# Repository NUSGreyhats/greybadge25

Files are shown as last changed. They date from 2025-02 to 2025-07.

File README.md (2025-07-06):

# greybadge25
GreyCTF 2025 Badge (Greymecha Army)

1. [Instruction Manual](https://docs.google.com/presentation/d/1nLdjBvxjxtfjGmfyWnxctUPe7XqL7leBmsDQaAjqEwk/edit?usp=sharing)
2. [Slides for Badge Talk](https://docs.google.com/presentation/d/1yoPuX5LA_Zj3ds3s_bZVRaBWZWmjrsSOJFy59PNaYqE/edit?usp=sharing)

## Repository Structure
```
.
├── firmware
│   ├── circuitpython_frozen_leaky.uf2  # CircuitPython firmware to flash
│   ├── ecp5                            # FPGA-related files                   
│   └── rp2350
│       ├── art                         # Greycat animation files (thanks shuqing!)
│       ├── filesystem                  # Filesystem to copy into CircuitPython (includes challenges)
│       ├── solutions                   # Solution scripts
│       └── src_chall                   # Raw challenge files for reference
├── hardware
│   ├── artwork                         # Artwork used on the PCB (thanks shuqing!)
│   ├── fpga_placement.svg              # High level reference for how the FPGA pins were used
│   ├── greybadge_pcb                   # KICAD files
│   ├── JLCPCB.kicad_dru
│   └── kicad_libraries
└── README.md
```

## Firmware Set Up Guide
1. Connect the PCB to your computer. It will mount as a USB drive named RPI_RP2.
2. From the `/firmware` folder, drag & drop the file `circuitpython_frozen_leaky.uf2` onto the RPI_RP2 drive.
3. This should restart the badge and it will appear as a new USB drive called CIRCUITPYTHON.
4. Open `/firmware/rp2350/filesystem` on your computer and copy everything inside that folder to the CIRCUITPYTHON drive.
5. Your badge is set up!

## Hardware Ordering Guide
Refer to `Prototype 3 Order` under Releases.

Feel free to update the BOM to remove the oscillator for the FPGA as it is expensive and not strictly necessary.

Ordering on JLCPCB:
1. Upload the GERBER into the order page.
2. For the PCB Fab options, we recommend mostly using the defaults, but keep the following options in mind:
    - Finishing: HASL (HASL is fine, though we recommend ENIG for higher quantities as the extra cost scales well and is better for BGA soldering.)
    - To customize the main PCB colour, update the soldermask colour.
    - To have it assembled, tick the option below. You would likely want to choose to assemble both sides, which requires the standard assembly (not economic assembly).
3. Select the BOM/CPL if you chose to have it assembled.

There are several things you will need to order separately (and solder on).
1. Screen: [Taobao Link](https://item.taobao.com/item.htm?id=784228754299), choose the 焊接12P option.
2. Battery: You can either use a LIPO with JST-PH connector or solder 3x AA batteries.
    - LiPo Battery: [Taobao Link](https://item.taobao.com/item.htm?id=695205775685) We chose the 603040-750mAh option. If you want to have the plug rather than soldering the battery, contact the seller to install the 2.0-2P 反向公插 header (2.0mm pitch, 2 pin, reverse-orientation), which is essentially JST-PH, on the battery.
    - AA Battery Holder: [Taobao Link](https://detail.tmall.com/item.htm?id=533054527075).
    - 90 Degree Pinout Headers (or just solder wires)

## FPGA Tooling

A sample FPGA project is in `/firmware/ecp5/uart_coprocessor`. The tooling needed to be installed is as such

```
sudo apt install openFPGALoader # only needed if you use an external fpga jtag programmer
sudo apt install yosys
sudo apt install nextpnr-ecp5
sudo apt install fpga-trellis
```

Afterwards, you can just run `make clean` and `make` to generate the bitstream.

You can upload through the RP2350 in the `hardware.fpga` libraries

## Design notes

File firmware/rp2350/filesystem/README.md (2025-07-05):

# GreyMecha/Army

This is the GreyMecha/Army Firmware (for the RP part anyway). It's based off circuitpython, and includes various challenges.

## Images

To customise the badge with your own (`.jpg` and `.gif`), just put them in the `images` folder. 
Make sure they are 240x240 pixels.

You may use EzGif to convert a video to Gif format. https://ezgif.com/video-to-gif

You may also use EzGif to resize to 240 x 240 pixels. https://ezgif.com/maker

## Challenges

There are 2 kinds of challenges. 
`grey` challenges are ones which are released for GreyCTF 2025 Finals. If you are a finalist, you only need to care about these.
`fun` challenges, meanwhile, are just ones for fun. 

Grey Challenges
1. Hornet Revenge
2. Leaky Pin
3. Bricked Up
3. Shooting Flags
4. Secure Memory
5. CatCore

## Updates

This badge might receive firmware updates so do check NUS Greyhats Github for any updates!
https://github.com/NUSGreyhats

Can also check the creator's blog for eventual solutions and writeups!
https://hackin7-blog.vercel.app/

## Credits

Developers

1. Hackin7 
    - Main Badge System Designer
    - Concept, Artwork & Animations
    - PCB (Power, FPGA, Connectivity)
    - Firmware
2. itsme-zeix 
    - PCB (RP2350, LiPo, Power), Leaky Pin, Firmware
3. shuqing 
    - Artwork & Animations (They are so cute man)
4. Fieash
    - Bricked Up Challenge
5. sunshinefactory
    - zip file
6. Codekrodile
    - mirrortune
7. khian
    - Asteroids
8. sayomaki
    - Bad Apple

Thanks to these people for helping

1. zst123, rhgndf, sayomaki - Technical Advice
2. caprinux - For initiating the whole GreyHats Badge thing

and thanks to GreyHats and whoever else who made this possible!

For anyone who made anything cool with the badge, do share it on instagram/x and tag NUSGreyhats!

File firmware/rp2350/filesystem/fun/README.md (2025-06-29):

# Fun Challenges

### SMD Skills

Get a 48MHz oscillator from the staff. You can solder it to the badge, read the flag from UART.
Make sure to set the Solder Bridge to the right option. If in doubt ask Hackin7.

Once soldered, go to UART mode and send "@---------------B@" to the UART

### SunshineZip (sunshinefactory)

Check the zip.

### Fast Secure Memory (hackin7)

Secure Memory but at 50MHz instead of 10Hz
(Untested lmao but theoretically can work)

### Bricked Up Game v2 (Fieash/itsme-zeix)

Updates the Bricked Up Challenge to remove the challenge and add additional features to the gameplay more NES Tetris-like.

Replace `brick_game.mpy` in `/apps` with the `brick_game.py` found in this directory.

Changes include:
- Removal of Konami code for CTF challenge
- Addition of J, S and Z pieces
- Additon of Ghost piece (to aid gameplay)
- Addition of background music: Tetris theme song played with the buzzer
- Level system: Increases with score
- Gameplay/Music multipler: Increases (speeds up) with levels

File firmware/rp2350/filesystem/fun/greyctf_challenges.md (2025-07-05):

# Challenges

Challenges can be found at https://github.com/NUSGreyhats/greyctf25-challs-public/tree/main/finals/hardware 

## Hornet Revenge

### Details

I want revenge.

Stop the backend and run this in the Thonny REPL to start the challenge.

```python
from hornet_revenge import *
```

### Author

Hackin7

## Bricked Up

### Details
Hardware/Reverse

A classic game of brick! 

### Author
fieash

## Leaky Pin

### Details

I wonder if there's something special in the secret pin....

Stop the backend and run this in the Thonny REPL to start the challenge.

```python
from leaky_gpio25 import *
```

### Author

itsme-zeix

## Shooting Flags

### Details

We have some Secure Armed Forces (SAF) on our badge. They are well trained to follow instructions and patterns.

```verilog
module shooting_flags #(
    parameter CLK_FREQ = 48_000_000 // not the actual clock frequency
) (
    input clk, input got_commanding_officer, output [7:0] cats
);
    //// Shooting Rate ////////////////////////////////////////////////////
    // Create a new clock
    reg [31:0] counter_shooting = 0;
    reg clk_shooting = 0;
    always @ (posedge clk) begin
        counter_shooting <= counter_shooting + 1;
        if (counter_shooting == CLK_FREQ/30) begin
            clk_shooting <= ~clk_shooting;
            counter_shooting <= 0;
        end
    end
    
    reg [31:0] counter_wayang = 0;
    reg clk_wayang = 0;
    always @ (posedge clk) begin
        counter_wayang <= counter_wayang + 1;
        if (counter_wayang == CLK_FREQ/4) begin
            clk_wayang <= ~clk_wayang;
            counter_wayang <= 0;
        end
    end
    //// Shooting /////////////////////////////////////////////////////////
    localparam FLAG_LEN = 25;
    reg [7:0] flag[FLAG_LEN];
    always @ (*) begin
        // lmao no flag
    end

    reg [7:0] shooting = 8'b101;
    reg [7:0] shooting_flag = 8'b0;
    reg [$clog2(FLAG_LEN)-1:0] counter_display = 0;
    always @ (posedge clk_shooting) begin
        shooting <= shooting << 1 | shooting[7];
    end
    always @ (posedge clk_wayang) begin
        shooting_flag <= (
            flag[counter_display] << counter_display % 8 | 
            flag[counter_display] >> (8-counter_display%8)
        );
        counter_display <= (counter_display + 1) % FLAG_LEN;
    end
    /// LED output //////////////////////////////////////////////////////
    assign cats = (got_commanding_officer ? shooting_flag : shooting);

endmodule

/* in the top module it is used as such

wire [7:0] chall_shootingflags_leds;
shooting_flags #(.CLK_FREQ(CLK_FREQ)) chall_shootingflags (
    .clk(clk), 
    .got_commanding_officer(~btn[2]),
    .cats(chall_shootingflags_leds)
);

*/
```

### Author

Hackin7

## Secure Memory

### Details

It's security at the hardware level so it must be secure right?

Clock Frequency - 15Hz

Verilog Reference

```verilog
// Code your design here
module regular_synchronous_memory(input clk, input [4:0] address, output reg [7:0] value);
	// memory retrieval
	always @ (posedge clk) begin // 10Hz
		value <= (
            // lmao you think i'll just give you the flag here? go extract it from your catcore.
			0
		);
	end
endmodule

module secure_memory(input clk, input [4:0] address, output [7:0] value);
	wire [4:0] mem_address;
	wire [7:0] mem_value;
	regular_synchronous_memory mem (clk, mem_address, mem_value);
	assign mem_address = address;
    assign value = ( mem_address == 5'd31 ? mem_value : "?" );
endmodule

/* 
At the top module
----------------------
assign chall_secmem_address = interconnect[4:0];
assign pmod_j2 = (
    mode == MODE_CHALL_SECURE_MEM ? chall_secmem_value : 
    8'bzzzzzzzz
);

Pinouts
-----------------------
LOCATE COMP "pmod_j2[0]" SITE "A14";
IOBUF PORT  "pmod_j2[0]" IO_TYPE=LVCMOS25;
LOCATE COMP "pmod_j2[1]" SITE "A13";
IOBUF PORT  "pmod_j2[1]" IO_TYPE=LVCMOS25;
LOCATE COMP "pmod_j2[2]" SITE "A12";
IOBUF PORT  "pmod_j2[2]" IO_TYPE=LVCMOS25;
LOCATE COMP "pmod_j2[3]" SITE "A11";
IOBUF PORT  "pmod_j2[3]" IO_TYPE=LVCMOS25;
LOCATE COMP "pmod_j2[4]" SITE "B14";
IOBUF PORT  "pmod_j2[4]" IO_TYPE=LVCMOS25;
LOCATE COMP "pmod_j2[5]" SITE "B13";
IOBUF PORT  "pmod_j2[5]" IO_TYPE=LVCMOS25;
LOCATE COMP "pmod_j2[6]" SITE "B12";
IOBUF PORT  "pmod_j2[6]" IO_TYPE=LVCMOS25;
LOCATE COMP "pmod_j2[7]" SITE "B11";
IOBUF PORT  "pmod_j2[7]" IO_TYPE=LVCMOS25;
*/
```

Solution Template

```python
import board
import digitalio
import time
import hardware.fpga

hardware.hw_state["fpga_overlay"].deinit()
if input("type something to update fpga: ") != "":
    h = hardware.fpga.upload_bitstream("/hardware/bitstreams/main.bit")
    h.deinit()

fpga_interconnect_pins = [board.GP8, board.GP9, board.GP10, board.GP11,	board.GP12, board.GP13, board.GP14, board.GP15]
rp2350_pmod_pins = [board.GP27, board.GP16, board.GP23, board.GP25, board.GP26, board.GP28, board.GP22, board.GP24]

### FPGA Interconnect
def overlay_interconnect_pins():
    dio = []
    for p in fpga_interconnect_pins:
        d = digitalio.DigitalInOut(p)
        d.direction = digitalio.Direction.OUTPUT
        dio.append(d)
    return dio

def pmod_pins():
    dio = []
    for p in rp2350_pmod_pins:
        if p == None: pass
        d = digitalio.DigitalInOut(p)
        d.direction = digitalio.Direction.INPUT
        dio.append(d)
    return dio

interconnect = overlay_interconnect_pins()
pmod = pmod_pins()

fpga_mode = [0, 1, 0]
interconnect[7].value = 0
interconnect[6].value = 1
interconnect[5].value = 0

def read_char():
    value = 0
    for p in range(len(pmod)):
        if pmod[p] == None: pass
        value |= pmod[p].value << p;
    return chr(value)

def set_address(addr):
    addr_bits = [0, 0, 0, 0, 0]
    addr_val = addr
    for i in range(len(addr_bits)):
        addr_bits[i] = addr_val % 2
        addr_val = addr_val // 2
    print("Address:",addr, addr_bits)
    for v in range(len(addr_bits)):
        interconnect[v].value = addr_bits[v]

### Insert Solution Code Below
```

### Author

Hackin7

## CatCore

### Details

Here at GreyCatTheFlag we have experience managing cats of different types. We have elmocat, we have jrocat, we have GPMGcat, and much more. 
You can now leverage our year of experience with CatCore Hyper, the latest version of our Hardware Coprocessor, specifically designed for managing cats.

Worried about security? No worries, being cat experts we have made sure that no one can anyhow mobilise your cats or show the white flag.
Only we can do it lmao.

### Relevant Files

Read the CatCore Hyper Datasheet in `/hardware`

### Author

Hackin7

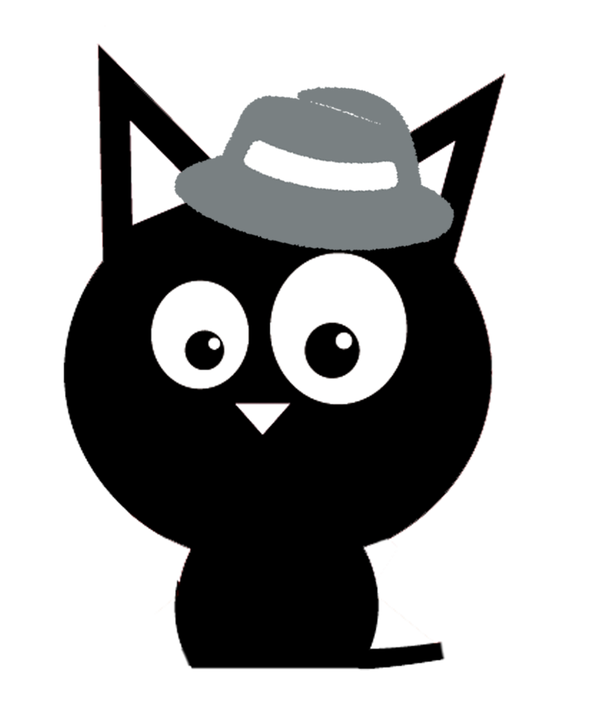
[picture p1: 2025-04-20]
hardware/artwork/greyhats.png

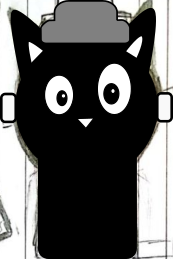
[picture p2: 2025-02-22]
hardware/artwork/mecha.png

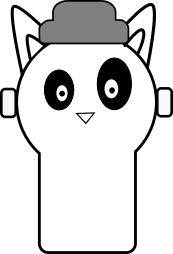
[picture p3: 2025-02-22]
hardware/artwork/greycat_outline.png

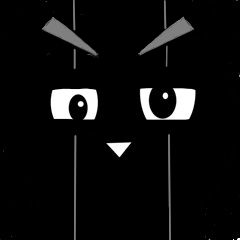
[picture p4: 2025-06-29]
firmware/rp2350/filesystem/image/greymecha_sian.jpg

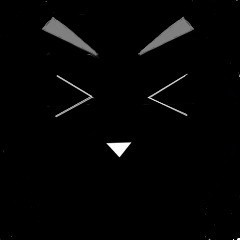
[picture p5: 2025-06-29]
firmware/rp2350/filesystem/image/greycat_peak.jpg

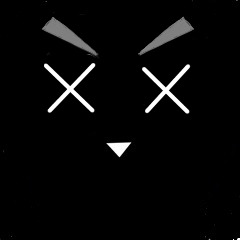
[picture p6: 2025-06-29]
firmware/rp2350/filesystem/image/greycat_dead.jpg

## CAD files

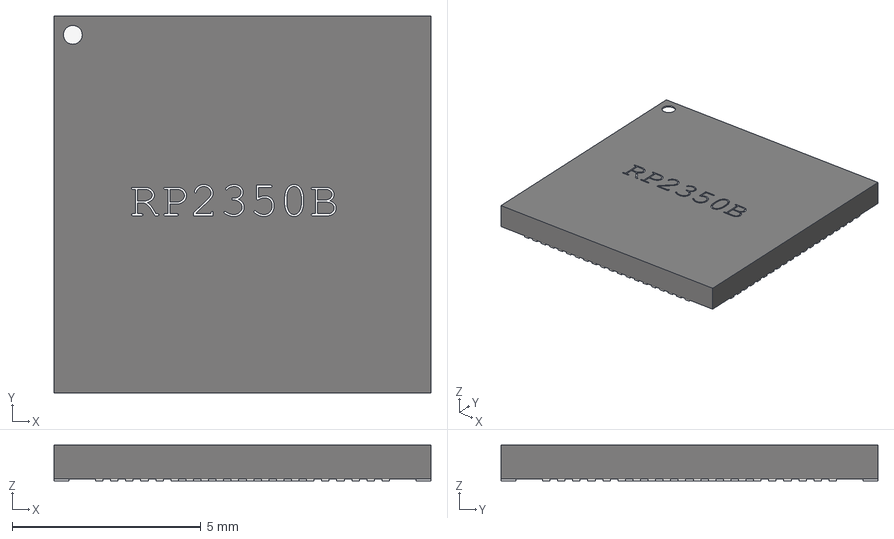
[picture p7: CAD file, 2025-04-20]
hardware/kicad_libraries/custom/3d_models/RP2350_QFN80.step
10.0 x 10.0 x 0.95 mm

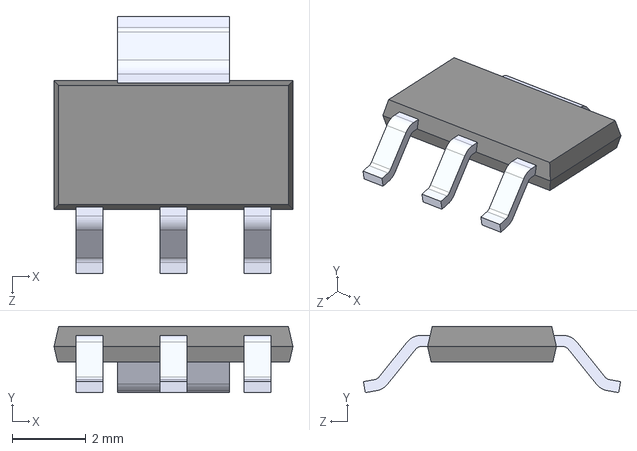
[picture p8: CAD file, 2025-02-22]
hardware/kicad_libraries/custom/3d_models/AMS1117-3.3.step
6.50 x 1.80 x 7.00 mm

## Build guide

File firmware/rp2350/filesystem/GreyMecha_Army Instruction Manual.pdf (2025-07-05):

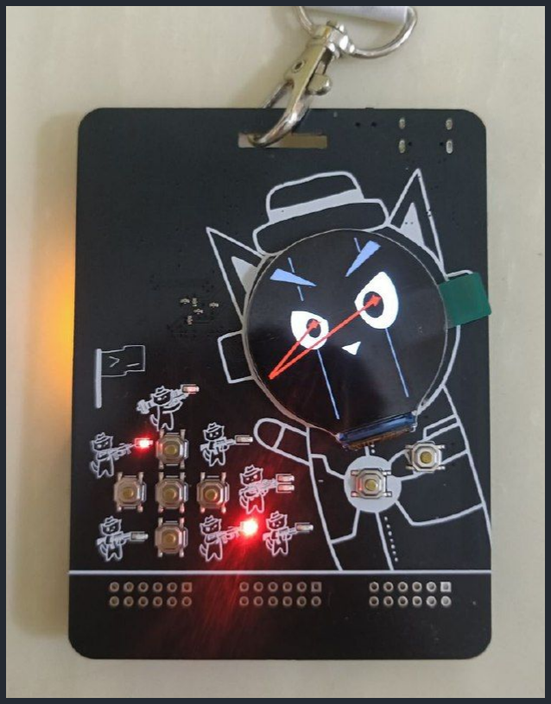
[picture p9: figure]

# GreyMecha/Army

## The GreyCTF 2025 badge

## Instructions

# Menu Options

1. Hi I'm Locked In (Does nothing)
2. Live Firing
3. Animation
4. Face (Images)
5. Music
6. Brick Game
7. Brick Good
8. Asteroids
9. Controller (USB HID Controller)
- "When I saw Loading
FPGA I thought it was
a joke"
- | It wasn't a joke - | that guy spent half the

CTF doing the FPGA
challs

# Design

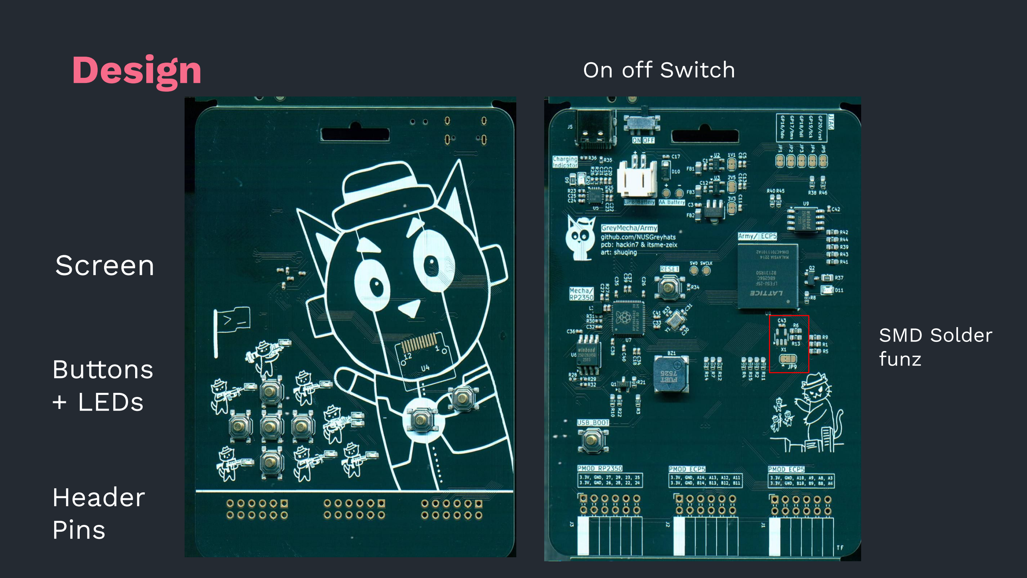
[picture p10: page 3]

## Screen

SMD Solder
funz

On off Switch

### Buttons + LEDs

### Header Pins

# Features

## pew pew pew

# Menu(s)

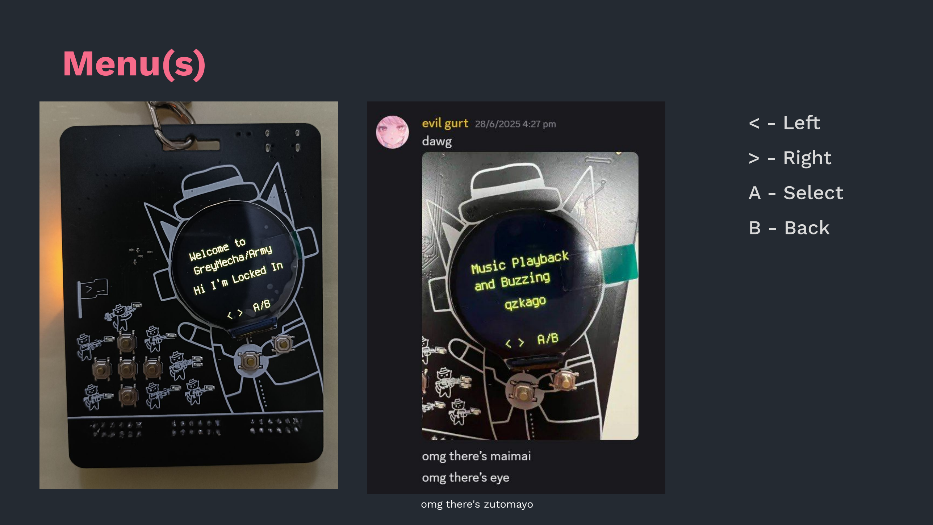
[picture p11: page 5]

< - Left
> - Right
A - Select
B - Back

omg there's zutomayo

# Live Firing

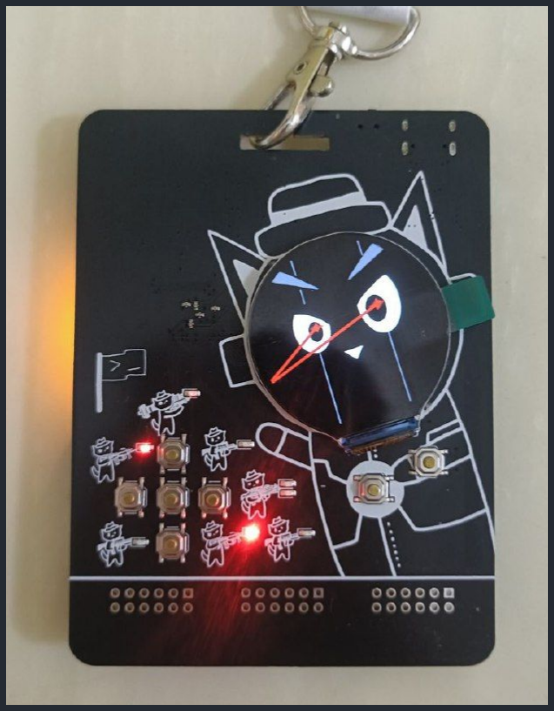
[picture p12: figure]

Hold down A/ B
- Quit Live Firing

Hold down B on startup
- Disable Buzzer

pew pew pew
beep
aahahahah

# Animation/ Face

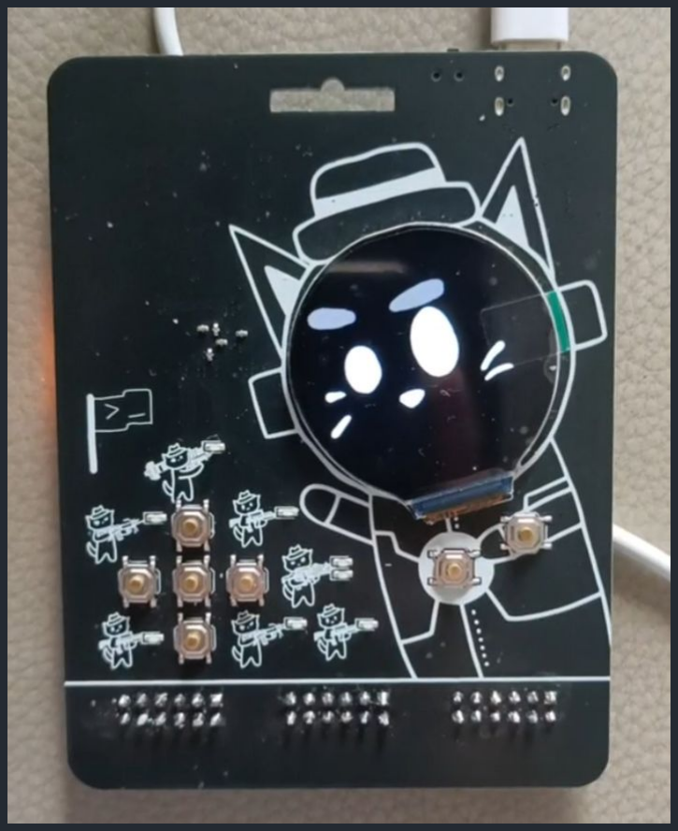
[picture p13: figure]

< > | Cycle through faces/ animations
A | Pause Animations
Long press A | Toggle LEDs
B | Back

# Games

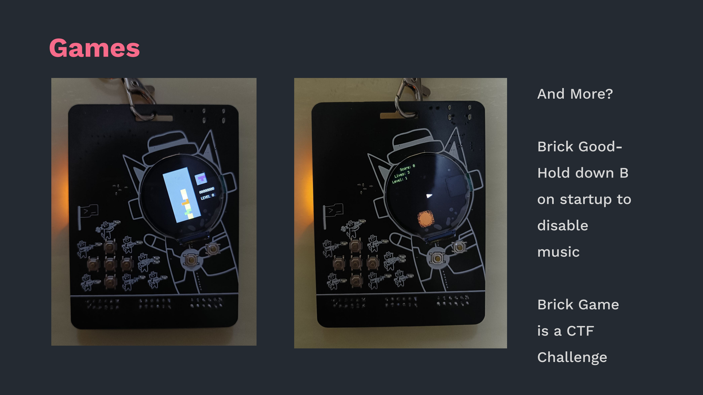
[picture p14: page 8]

And More?

Brick Good-Hold down B
on startup to
disable
music

Brick Game
is a CTF
Challenge

# Challenges

## pew pew pew

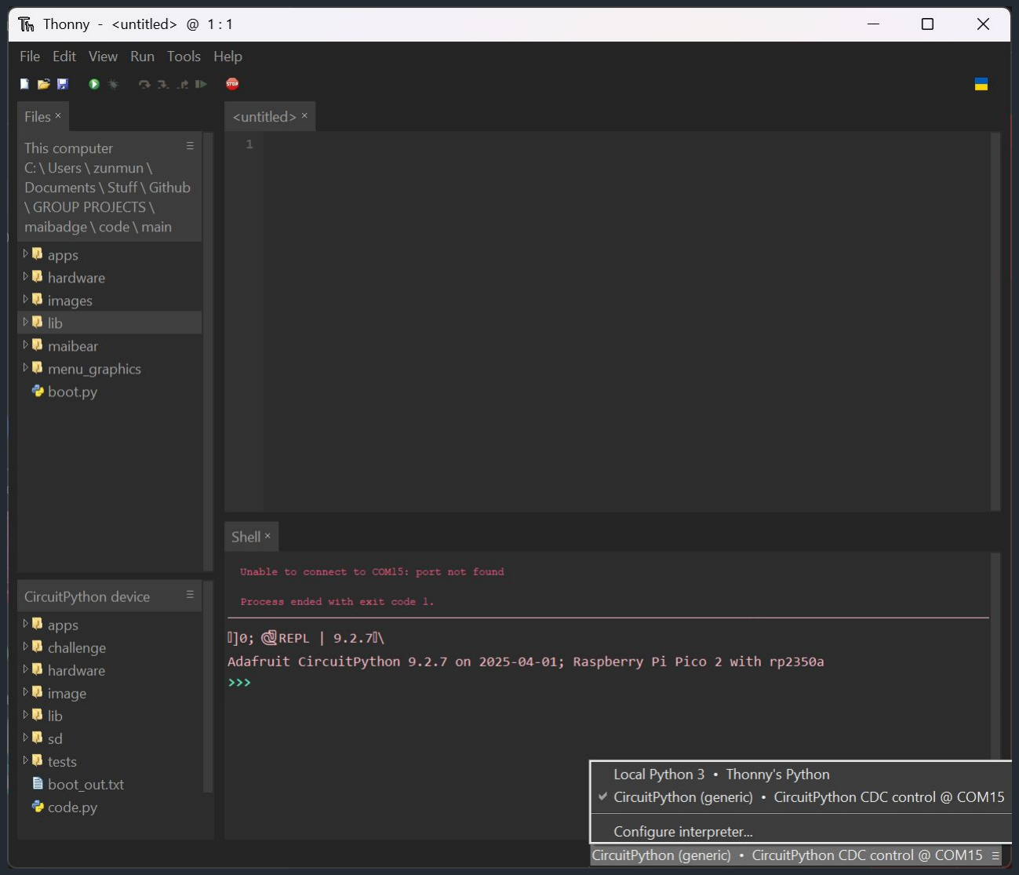
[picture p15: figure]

# USB

The badge runs
CircuitPython

It should show up as a
USB Flash Drive to
interact with the files

You can use an IDE like
https://thonny.org/ or
https://code.circuitpython.org/ (https://code.circuitpython.org/) to interact with it

# Updating Firmware

## ooh new game?

# Update Firmware

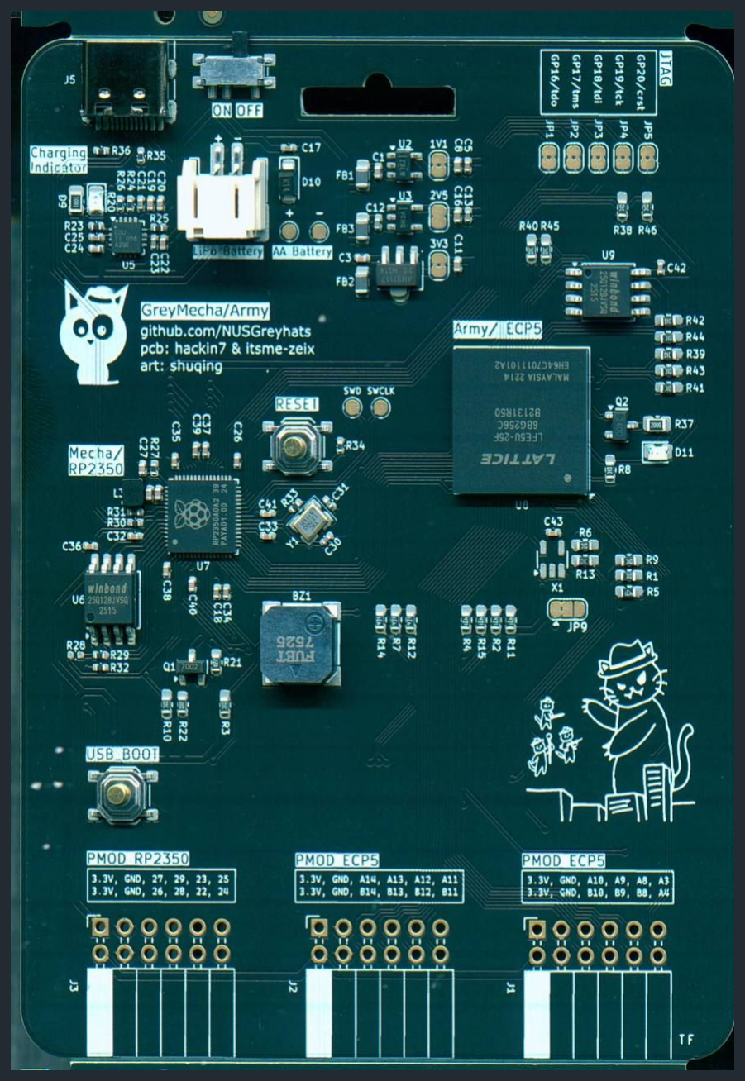
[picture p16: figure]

Reset the board while holding down the USB BOOT button

Download the uf2 from
https://github.com/NUSGreyhats/greybadge25/releas es (https://github.com/NUSGreyhats/greybadge25/releases) and drag it to the badge

should be all good!

# Stuff I'm too lazy to fix manually

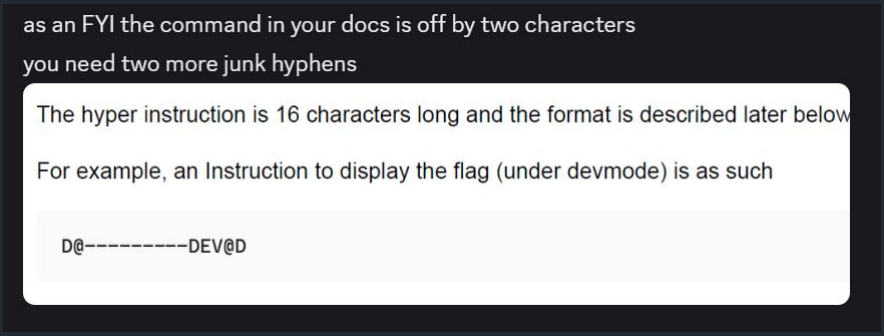
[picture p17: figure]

# Resources

https://hackin7-blog.vercel.app/https://github.com/NUSGreyhats/greybadge25

Other stuff
- To generate bitstream for the FPGA use yosys and nextpnr-ecp5
- You can install on wsl, make the sample projects (from github), and transfer over to GreyMecha/Army

# GreyMecha/Army!

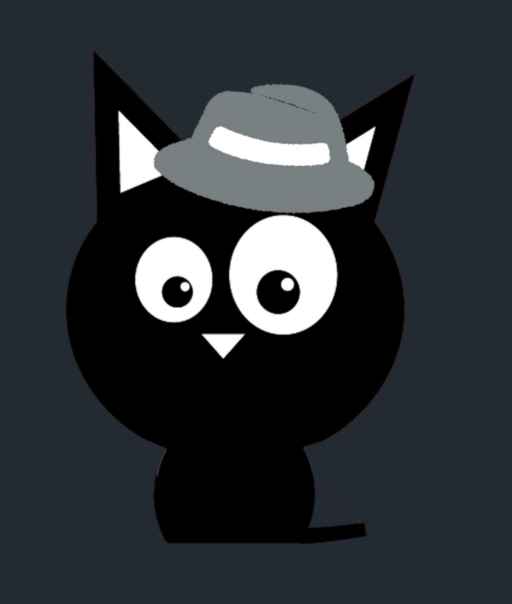
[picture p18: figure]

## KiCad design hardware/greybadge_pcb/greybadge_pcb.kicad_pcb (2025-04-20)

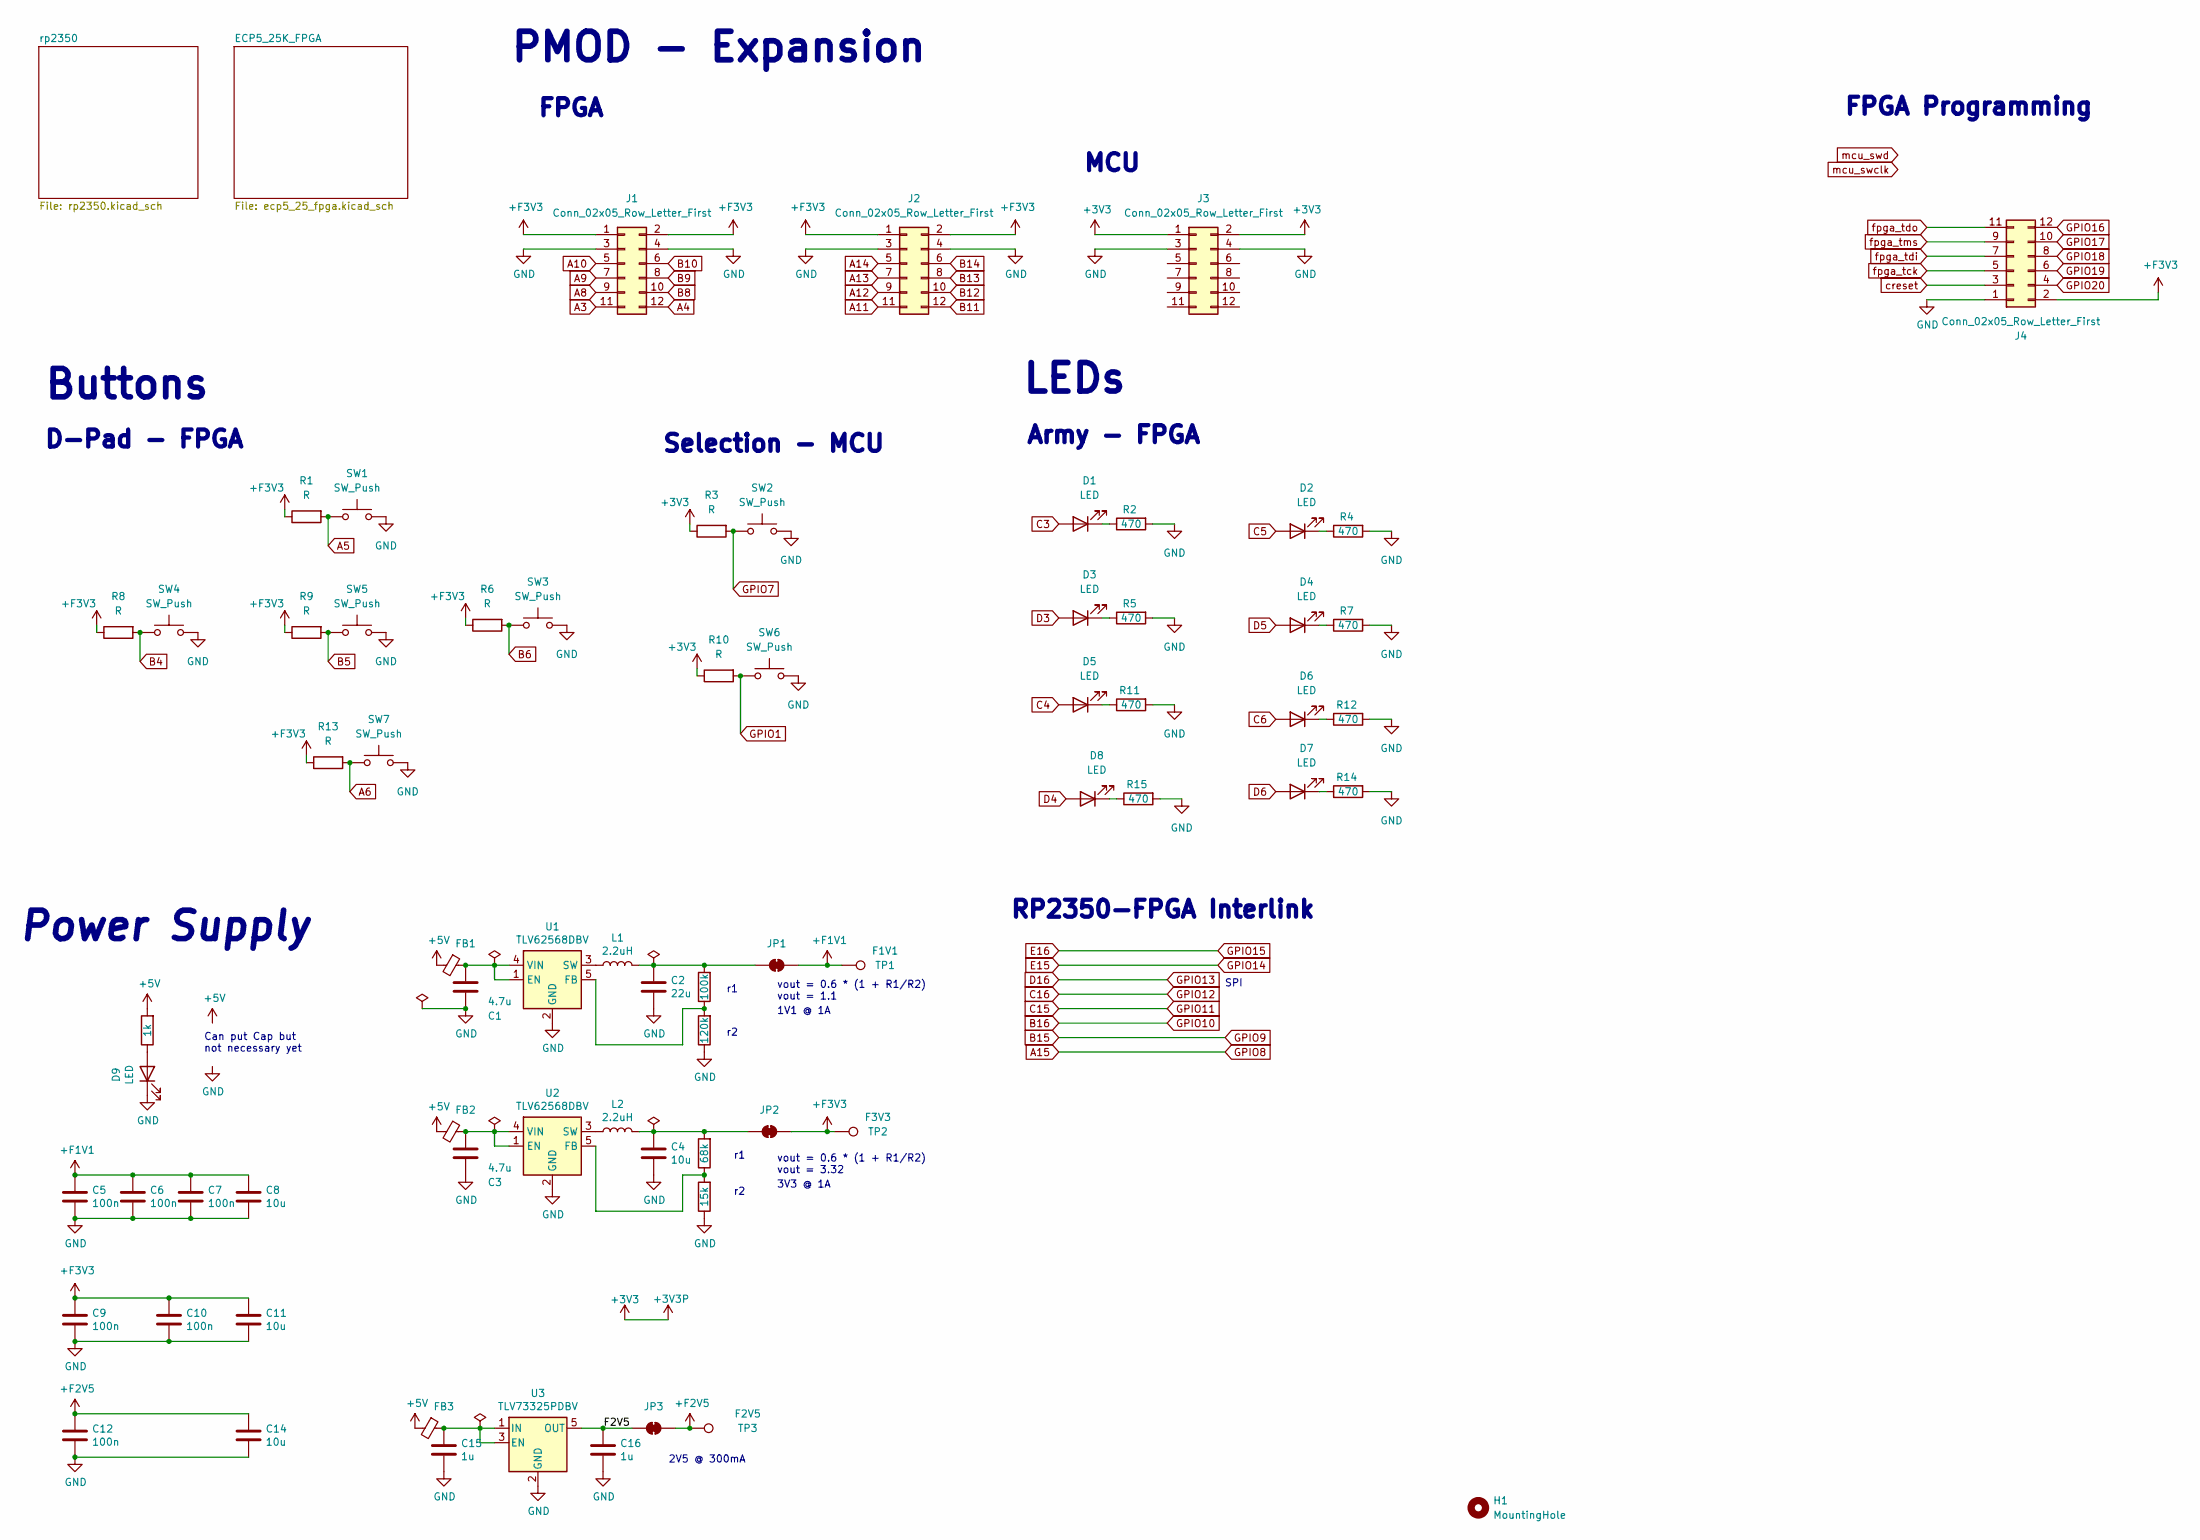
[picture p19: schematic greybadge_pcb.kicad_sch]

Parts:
C1, C3: 4.7u; C_0402_1005Metric
C2: 22u; C_0402_1005Metric
C4, C8, C11, C14: 10u; C_0402_1005Metric
C5, C6, C7, C9, C10, C12: 100n; C_0402_1005Metric
C15, C16: 1u; C_0402_1005Metric
D1, D2, D3, D4, D5, D6, D7, D8: LED; LED_0603_1608Metric_Pad1.05x0.95mm_HandSolder
D9: LED; LED_0805_2012Metric
FB1, FB2, FB3: Ferrite_Bead_Small; L_0805_2012Metric
H1: MountingHole; MountingHole_3mm_Pad
J1, J2, J3, J4: Conn_02x05_Row_Letter_First; PinSocket_2x06_P2.54mm_Horizontal
JP1, JP2, JP3: SolderJumper_2_Bridged; SolderJumper-2_P1.3mm_Bridged2Bar_RoundedPad1.0x1.5mm
L1, L2: 2.2uH; L_Taiyo-Yuden_NR-40xx
R1, R3, R6, R8, R9, R10, R13: R; R_0603_1608Metric_Pad0.98x0.95mm_HandSolder
R2, R4, R5, R7, R11, R12, R14, R15: 470; R_0603_1608Metric_Pad0.98x0.95mm_HandSolder
R16: 100k; R_0805_2012Metric
R17: 1k; R_0805_2012Metric
R18: 120k; R_0805_2012Metric
R19: 68k; R_0805_2012Metric
R20: 15k; R_0805_2012Metric
SW1, SW2, SW3, SW4, SW5, SW6, SW7: SW_Push; SW_Push_1P1T_XKB_TS-1187A
TP1: F1V1; TestPoint_THTPad_D1.0mm_Drill0.5mm
TP2: F3V3; TestPoint_THTPad_D1.0mm_Drill0.5mm
TP3: F2V5; TestPoint_THTPad_D1.0mm_Drill0.5mm
U1, U2: TLV62568DBV; SOT-23-5
U3: TLV73325PDBV; SOT-23-5

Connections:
+5V: FB1.2, FB2.2, FB3.2, R17.2; also elsewhere on the board
+F1V1: C5.1, C6.1, C7.1, C8.1, JP1.2 (B), TP1.1; also elsewhere on the board
+F2V5: C12.1, C14.1, JP3.2 (B), TP3.1; also elsewhere on the board
+F3V3: C9.1, C10.1, C11.1, J1.1, J1.2, J2.1, J2.2, J4.2, JP2.2 (B), R1.1, R6.1, R8.1, R9.1, R13.1, TP2.1; also elsewhere on the board
/F2V5: C16.1, JP3.1 (A), U3.5 (OUT)
A3: J1.11; also elsewhere on the board
A4: J1.12; also elsewhere on the board
A5: R1.2, SW1.2; also elsewhere on the board
A6: R13.2, SW7.2; also elsewhere on the board
A8: J1.9; also elsewhere on the board
A9: J1.7; also elsewhere on the board
A10: J1.5; also elsewhere on the board
A11: J2.11; also elsewhere on the board
A12: J2.9; also elsewhere on the board
A13: J2.7; also elsewhere on the board
A14: J2.5; also elsewhere on the board
B4: R8.2, SW4.2; also elsewhere on the board
B5: R9.2, SW5.2; also elsewhere on the board
B6: R6.2, SW3.2; also elsewhere on the board
B8: J1.10; also elsewhere on the board
B9: J1.8; also elsewhere on the board
B10: J1.6; also elsewhere on the board
B11: J2.12; also elsewhere on the board
B12: J2.10; also elsewhere on the board
B13: J2.8; also elsewhere on the board
B14: J2.6; also elsewhere on the board
C3: D1.2 (A); also elsewhere on the board
C4: D5.2 (A); also elsewhere on the board
C5: D2.2 (A); also elsewhere on the board
C6: D6.2 (A); also elsewhere on the board
D3: D3.2 (A); also elsewhere on the board
D4: D8.2 (A); also elsewhere on the board
D5: D4.2 (A); also elsewhere on the board
D6: D7.2 (A); also elsewhere on the board
GND: C1.2, C2.2, C3.2, C4.2, C5.2, C6.2, C7.2, C8.2, C9.2, C10.2, C11.2, C12.2, C14.2, C15.2, C16.2, D9.1 (K), J1.3, J1.4, J2.3, J2.4, J3.3, J3.4, J4.1, R2.2, R4.2, R5.2, R7.2, R11.2, R12.2, R14.2, R15.2, R18.1, R20.1, SW1.1, SW2.1, SW3.1, SW4.1, SW5.1, SW6.1, SW7.1, U1.2 (GND), U2.2 (GND), U3.2 (GND); also elsewhere on the board
GPIO1: R10.2, SW6.2; also elsewhere on the board
GPIO7: R3.2, SW2.2; also elsewhere on the board
GPIO16: J4.12; also elsewhere on the board
GPIO17: J4.10; also elsewhere on the board
GPIO18: J4.8; also elsewhere on the board
GPIO19: J4.6; also elsewhere on the board
GPIO20: J4.4; also elsewhere on the board
unnamed: D1.1 (K), R2.1
unnamed: D2.1 (K), R4.1
unnamed: D3.1 (K), R5.1
unnamed: D4.1 (K), R7.1
unnamed: D5.1 (K), R11.1
unnamed: D6.1 (K), R12.1
unnamed: D7.1 (K), R14.1
unnamed: D8.1 (K), R15.1
unnamed: D9.2 (A), R17.1
unnamed: C2.1, JP1.1 (A), L1.2, R16.2
unnamed: C4.1, JP2.1 (A), L2.2, R19.2
unnamed: C1.1, FB1.1, U1.1 (EN), U1.4 (VIN)
unnamed: R16.1, R18.2, U1.5 (FB)
unnamed: L1.1, U1.3 (SW)
unnamed: C3.1, FB2.1, U2.1 (EN), U2.4 (VIN)
unnamed: R19.1, R20.2, U2.5 (FB)
unnamed: L2.1, U2.3 (SW)
unnamed: C15.1, FB3.1, U3.1 (IN), U3.3 (EN)
creset: J4.3; also elsewhere on the board
fpga_tck: J4.5; also elsewhere on the board
fpga_tdi: J4.7; also elsewhere on the board
fpga_tdo: J4.11; also elsewhere on the board
fpga_tms: J4.9; also elsewhere on the board

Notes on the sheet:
3V3 @ 1A
SPI
PMOD - Expansion
D-Pad - FPGA
vout = 0.6 * (1 + R1/R2) vout = 1.1
FPGA Programming
1V1 @ 1A
Army - FPGA
Selection - MCU
LEDs
MCU
Can put Cap but not necessary yet
RP2350-FPGA Interlink
Power Supply
FPGA
Buttons
vout = 0.6 * (1 + R1/R2) vout = 3.32
2V5 @ 300mA

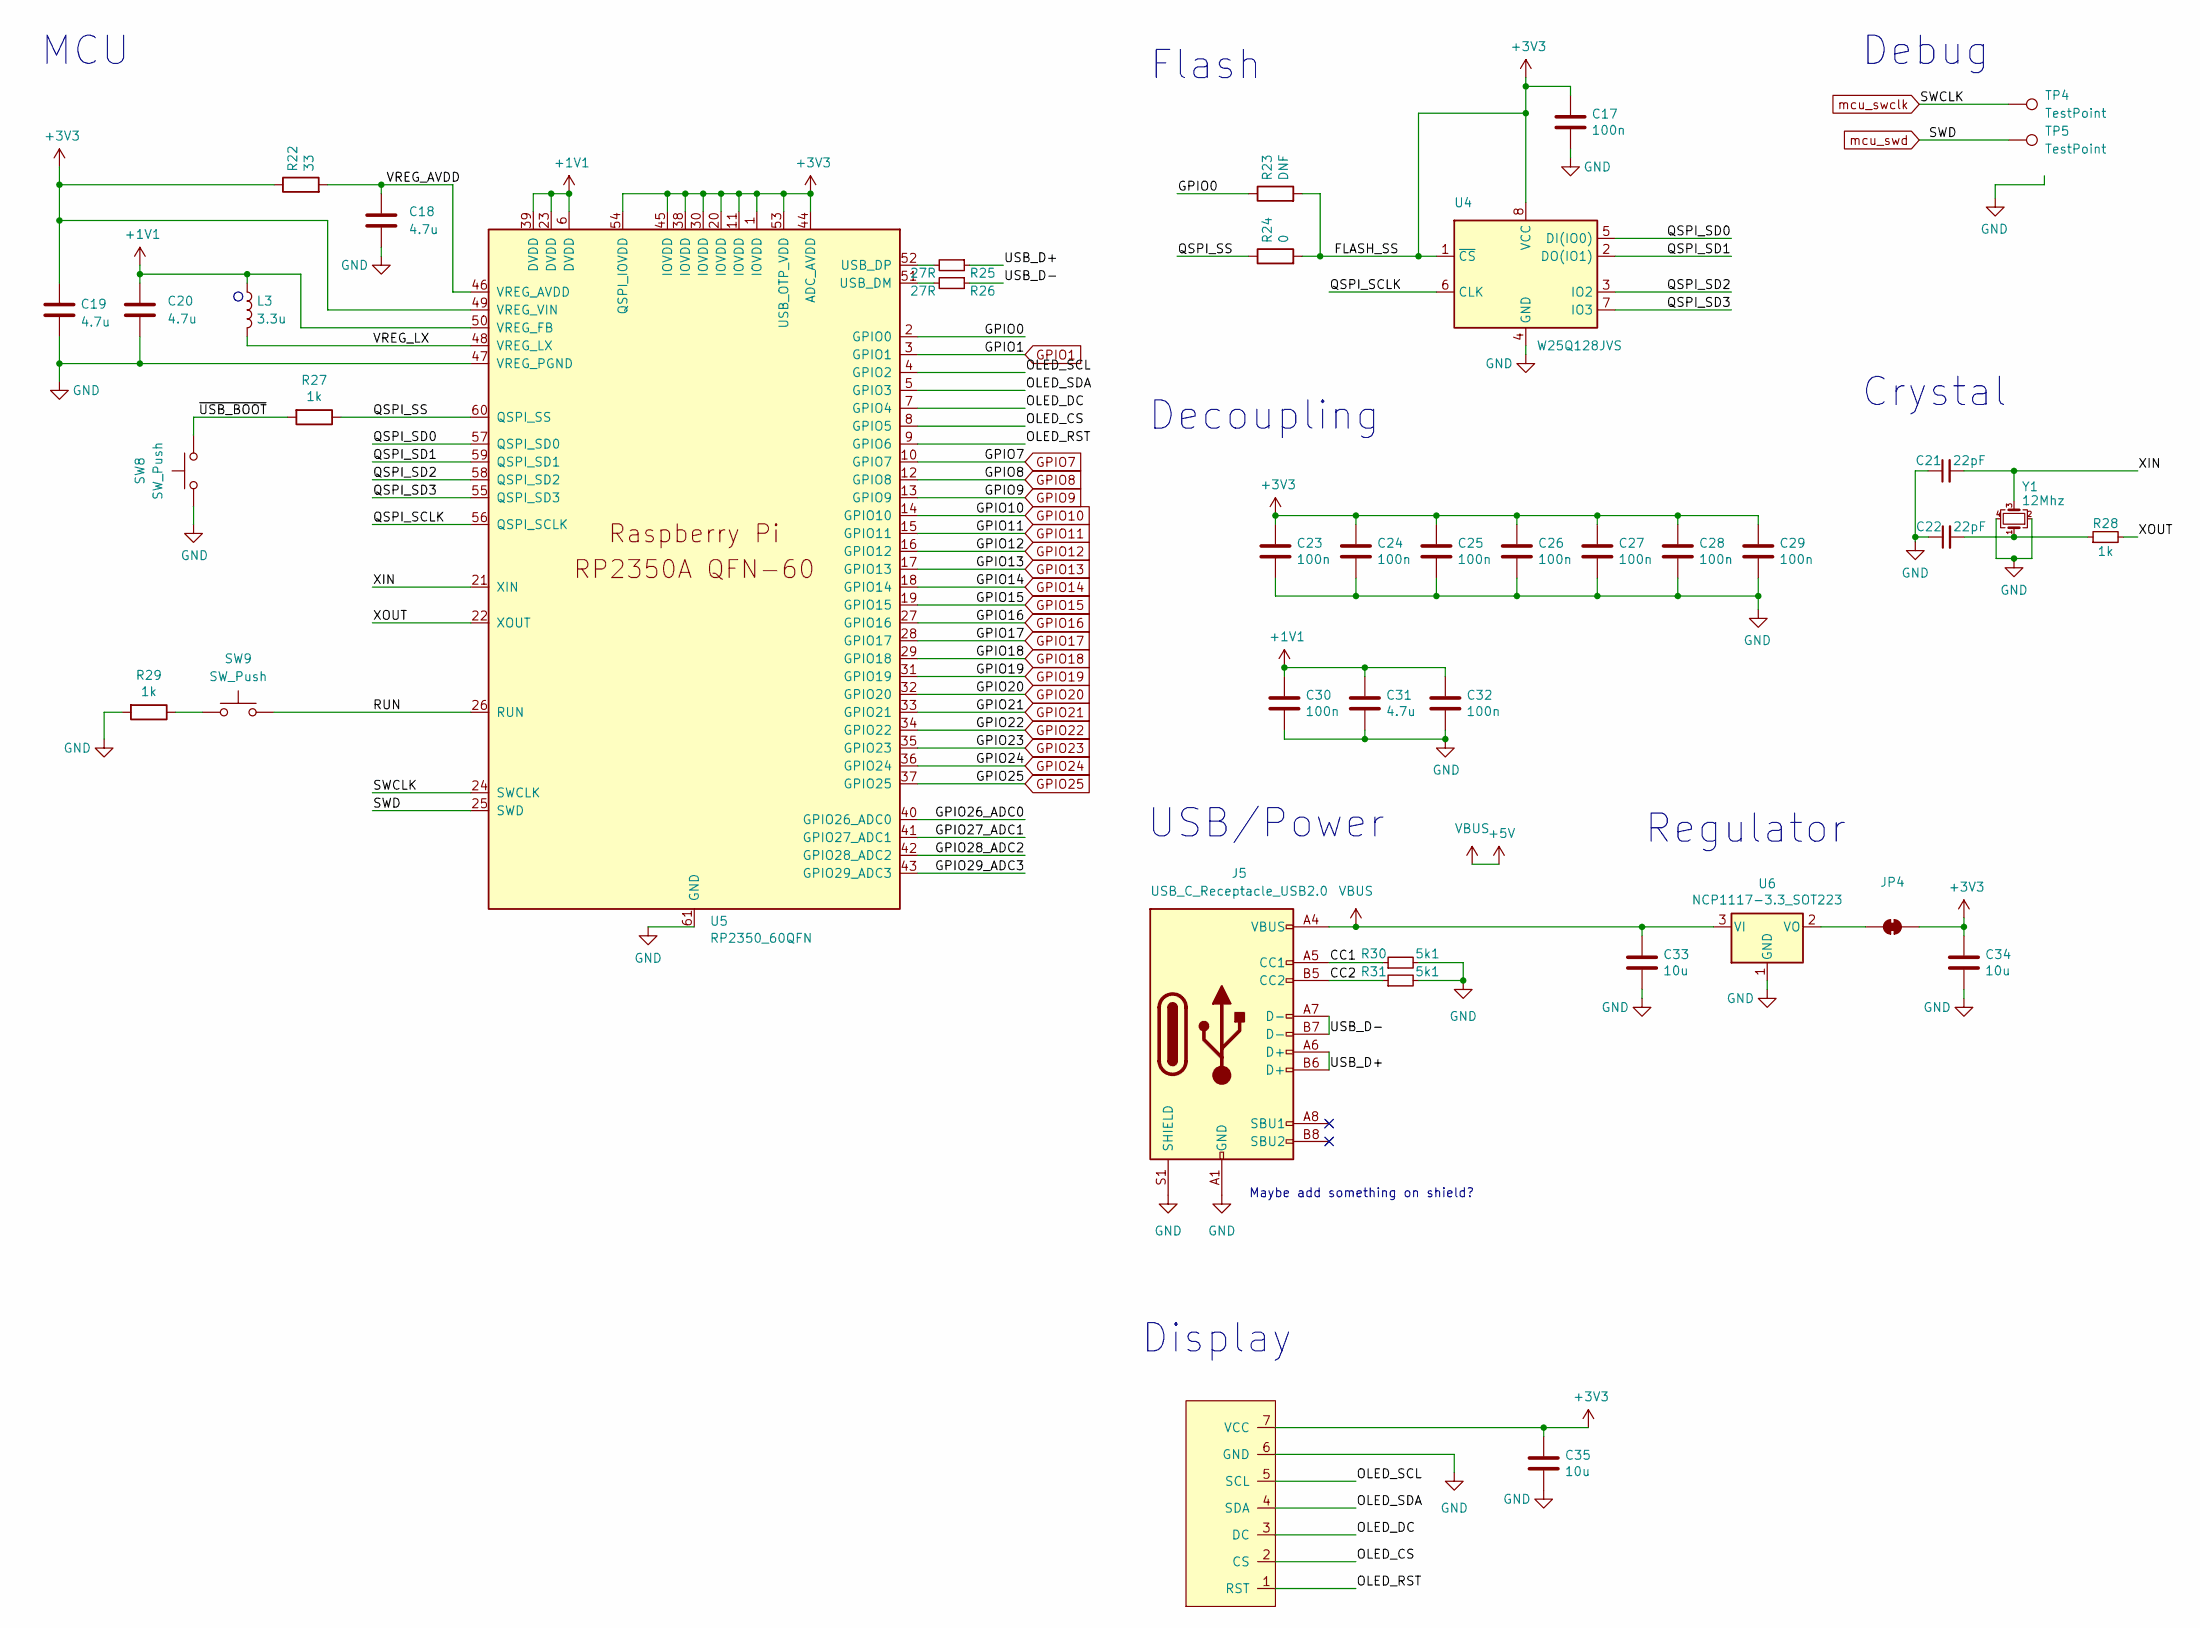
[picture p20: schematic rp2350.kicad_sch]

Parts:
C17, C23, C24, C25, C26, C27, C28, C29, C30, C32: 100n; C_0402_1005Metric
C18, C19, C20, C31: 4.7u; C_0402_1005Metric
C21, C22: 22pF; C_0402_1005Metric
C33, C34, C35: 10u; C_0402_1005Metric
GC9A1: CG9A01; GC9A01
J5: USB_C_Receptacle_USB2.0; USB_C_Receptacle_HRO_TYPE-C-31-M-12; LCSC C165948
JP4: SolderJumper_2_Bridged; SolderJumper-2_P1.3mm_Bridged2Bar_RoundedPad1.0x1.5mm
L3: 3.3u; L_pol_2016
R22: 33; R_0402_1005Metric
R23: DNF; R_0402_1005Metric
R24: 0; R_0402_1005Metric
R25, R26: 27R; R_0402_1005Metric
R27, R28, R29: 1k; R_0402_1005Metric
R30, R31: 5k1; R_0402_1005Metric; LCSC C25905
SW8, SW9: SW_Push; SW_Push_1P1T_XKB_TS-1187A
TP4, TP5: TestPoint; TestPoint_Pad_D1.5mm
U4: W25Q128JVS; SOIC-8_5.3x5.3mm_P1.27mm
U5: RP2350_60QFN; RP2350-QFN-60-1EP_7x7_P0.4mm_EP3.4x3.4mm_ThermalVias
U6: NCP1117-3.3_SOT223; SOT-223-3_TabPin2
Y1: 12Mhz; Crystal_SMD_3225-4Pin_3.2x2.5mm

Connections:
+1V1: C20.1, C30.1, C31.1, C32.1, L3.1, U5.6 (DVDD), U5.23 (DVDD), U5.39 (DVDD), U5.50 (VREG_FB)
+5V: C33.1, J5.A4 (VBUS), J5.A9 (VBUS), J5.B4 (VBUS), J5.B9 (VBUS), U6.3 (VI); also elsewhere on the board
/rp2350/CC1: J5.A5 (CC1), R30.1
/rp2350/CC2: J5.B5 (CC2), R31.1
/rp2350/GPIO0: R23.1, U5.2 (GPIO0)
/rp2350/GPIO26_ADC0: U5.40 (GPIO26_ADC0)
/rp2350/GPIO27_ADC1: U5.41 (GPIO27_ADC1)
/rp2350/GPIO28_ADC2: U5.42 (GPIO28_ADC2)
/rp2350/GPIO29_ADC3: U5.43 (GPIO29_ADC3)
/rp2350/OLED_CS: GC9A1.2 (CS), U5.8 (GPIO5)
/rp2350/OLED_DC: GC9A1.3 (DC), U5.7 (GPIO4)
/rp2350/OLED_RST: GC9A1.1 (RST), U5.9 (GPIO6)
/rp2350/OLED_SCL: GC9A1.5 (SCL), U5.4 (GPIO2)
/rp2350/OLED_SDA: GC9A1.4 (SDA), U5.5 (GPIO3)
/rp2350/QSPI_SCLK: U4.6 (CLK), U5.56 (QSPI_SCLK)
/rp2350/QSPI_SD0: U4.5 (DI(IO0)), U5.57 (QSPI_SD0)
/rp2350/QSPI_SD1: U4.2 (DO(IO1)), U5.59 (QSPI_SD1)
/rp2350/QSPI_SD2: U4.3 (IO2), U5.58 (QSPI_SD2)
/rp2350/QSPI_SD3: U4.7 (IO3), U5.55 (QSPI_SD3)
/rp2350/QSPI_SS: R24.1, R27.1, U5.60 (QSPI_SS)
/rp2350/RUN: SW9.1, U5.26 (RUN)
/rp2350/USB_D+: J5.A6 (D+), J5.B6 (D+), R25.1
/rp2350/USB_D-: J5.A7 (D-), J5.B7 (D-), R26.1
/rp2350/VREG_AVDD: C18.1, R22.2, U5.46 (VREG_AVDD)
/rp2350/VREG_LX: L3.2, U5.48 (VREG_LX)
/rp2350/XIN: C21.2, U5.21 (XIN), Y1.3
/rp2350/XOUT: R28.2, U5.22 (XOUT)
/rp2350/~USB_BOOT: R27.2, SW8.1
GND: C17.2, C18.2, C19.2, C20.2, C21.1, C22.1, C23.2, C24.2, C25.2, C26.2, C27.2, C28.2, C29.2, C30.2, C31.2, C32.2, C33.2, C34.2, C35.2, GC9A1.6 (GND), J5.A1 (GND), J5.A12 (GND), J5.B1 (GND), J5.B12 (GND), J5.S1 (SHIELD), R29.2, R30.2, R31.2, SW8.2, U4.4 (GND), U5.47 (VREG_PGND), U5.61 (GND), U6.1 (GND), Y1.2, Y1.4; also elsewhere on the board
GPIO1: U5.3 (GPIO1); also elsewhere on the board
GPIO7: U5.10 (GPIO7); also elsewhere on the board
GPIO16: U5.27 (GPIO16); also elsewhere on the board
GPIO17: U5.28 (GPIO17); also elsewhere on the board
GPIO18: U5.29 (GPIO18); also elsewhere on the board
GPIO19: U5.31 (GPIO19); also elsewhere on the board
GPIO20: U5.32 (GPIO20); also elsewhere on the board
GPIO21: U5.33 (GPIO21)
GPIO22: U5.34 (GPIO22)
GPIO23: U5.35 (GPIO23)
GPIO24: U5.36 (GPIO24)
GPIO25: U5.37 (GPIO25)
unnamed: C22.2, R28.1, Y1.1
unnamed: JP4.1 (A), U6.2 (VO)
unnamed: R29.1, SW9.2
unnamed: R26.2, U5.51 (USB_DM)
unnamed: R25.2, U5.52 (USB_DP)
mcu_swclk: TP4.1, U5.24 (SWCLK)
mcu_swd: TP5.1, U5.25 (SWD)

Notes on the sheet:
Debug
Crystal
Flash
Regulator
USB/Power
Maybe add something on shield?
MCU
Decoupling
Display

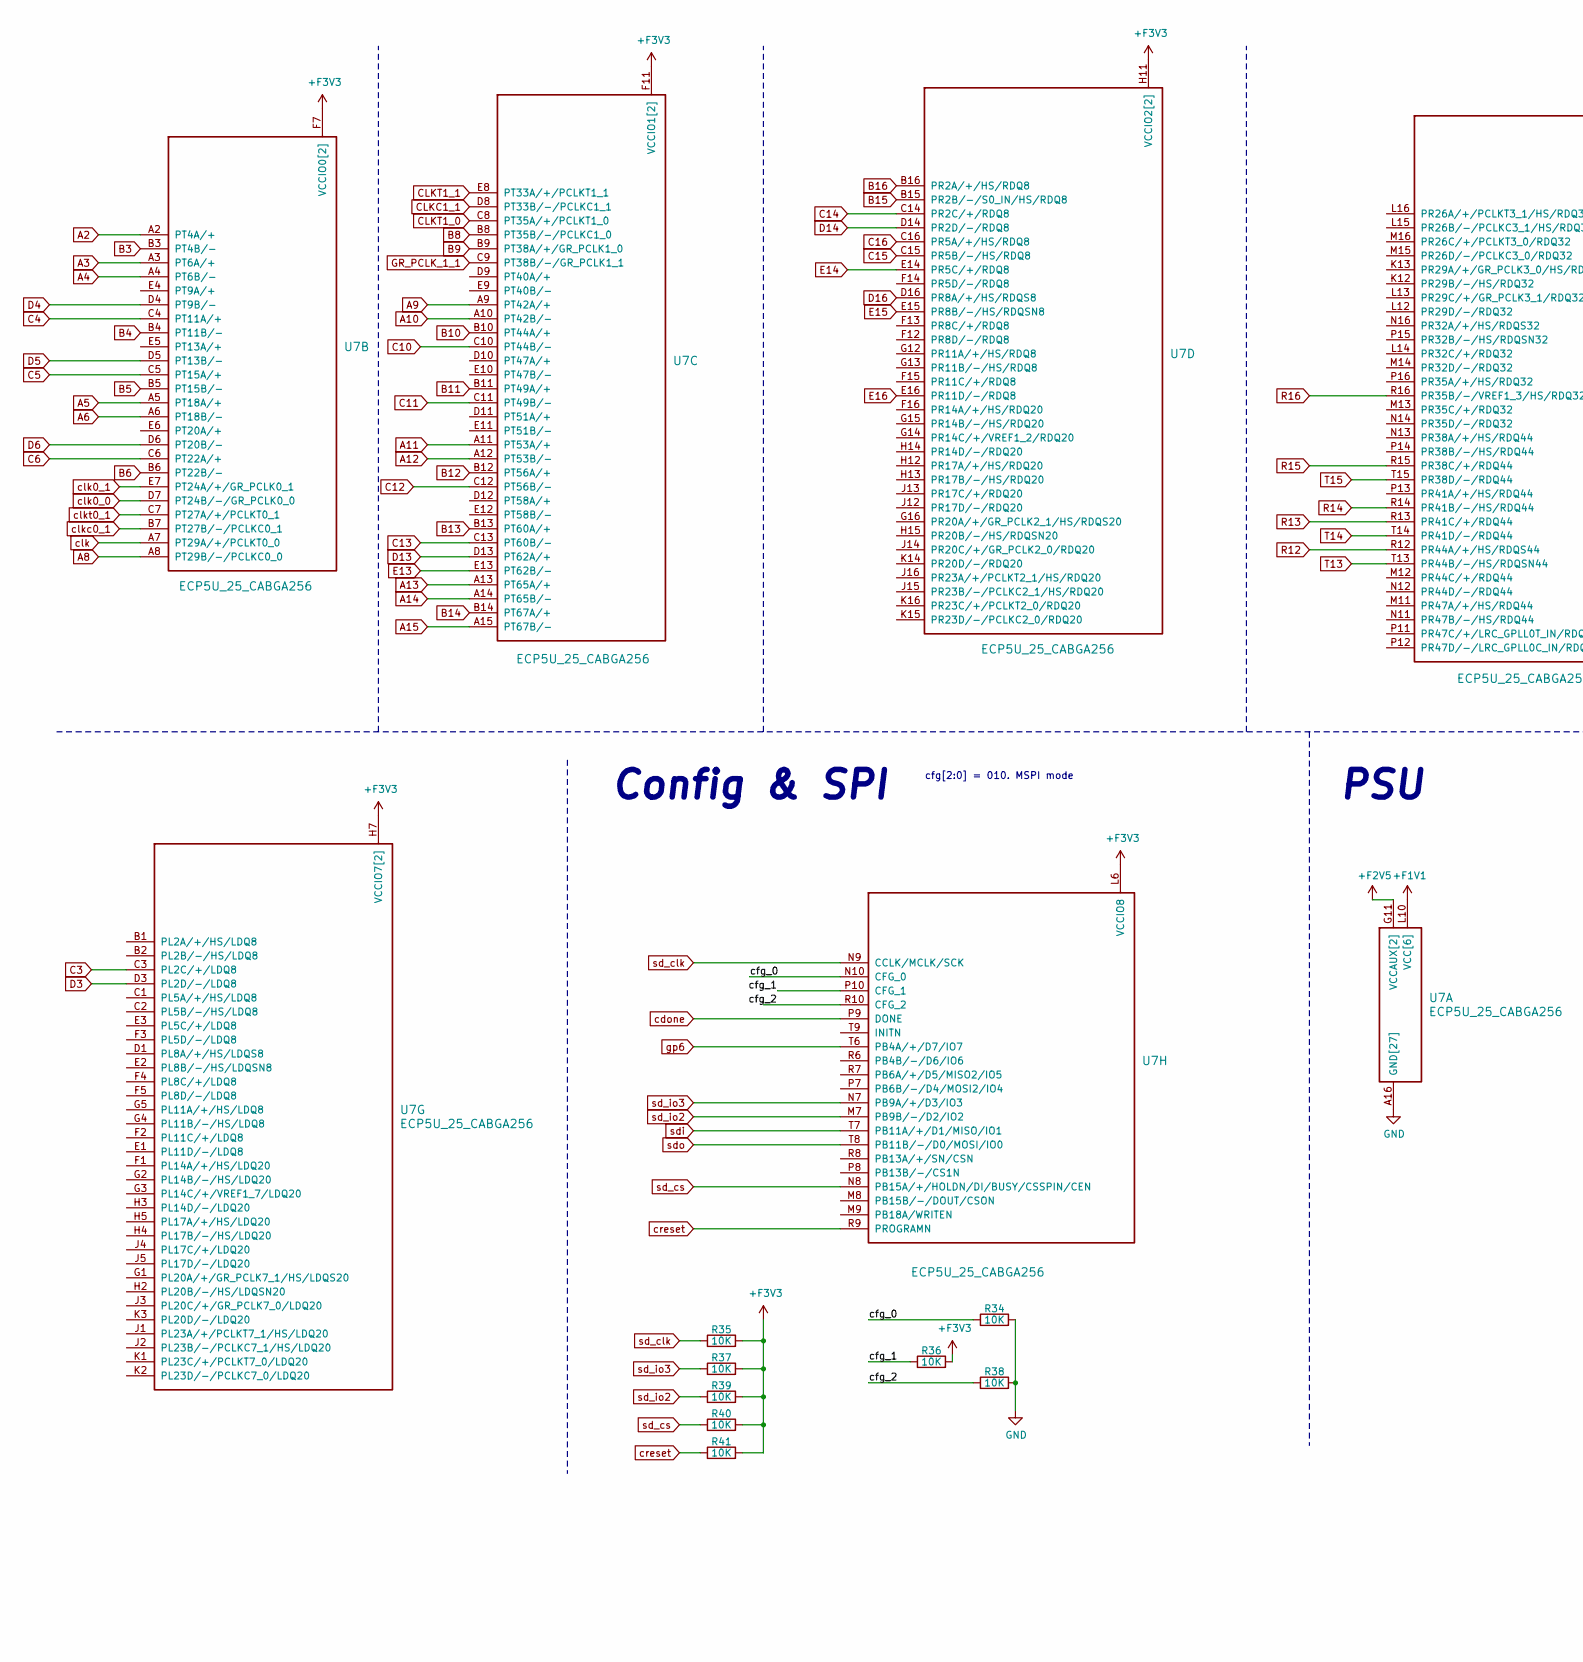
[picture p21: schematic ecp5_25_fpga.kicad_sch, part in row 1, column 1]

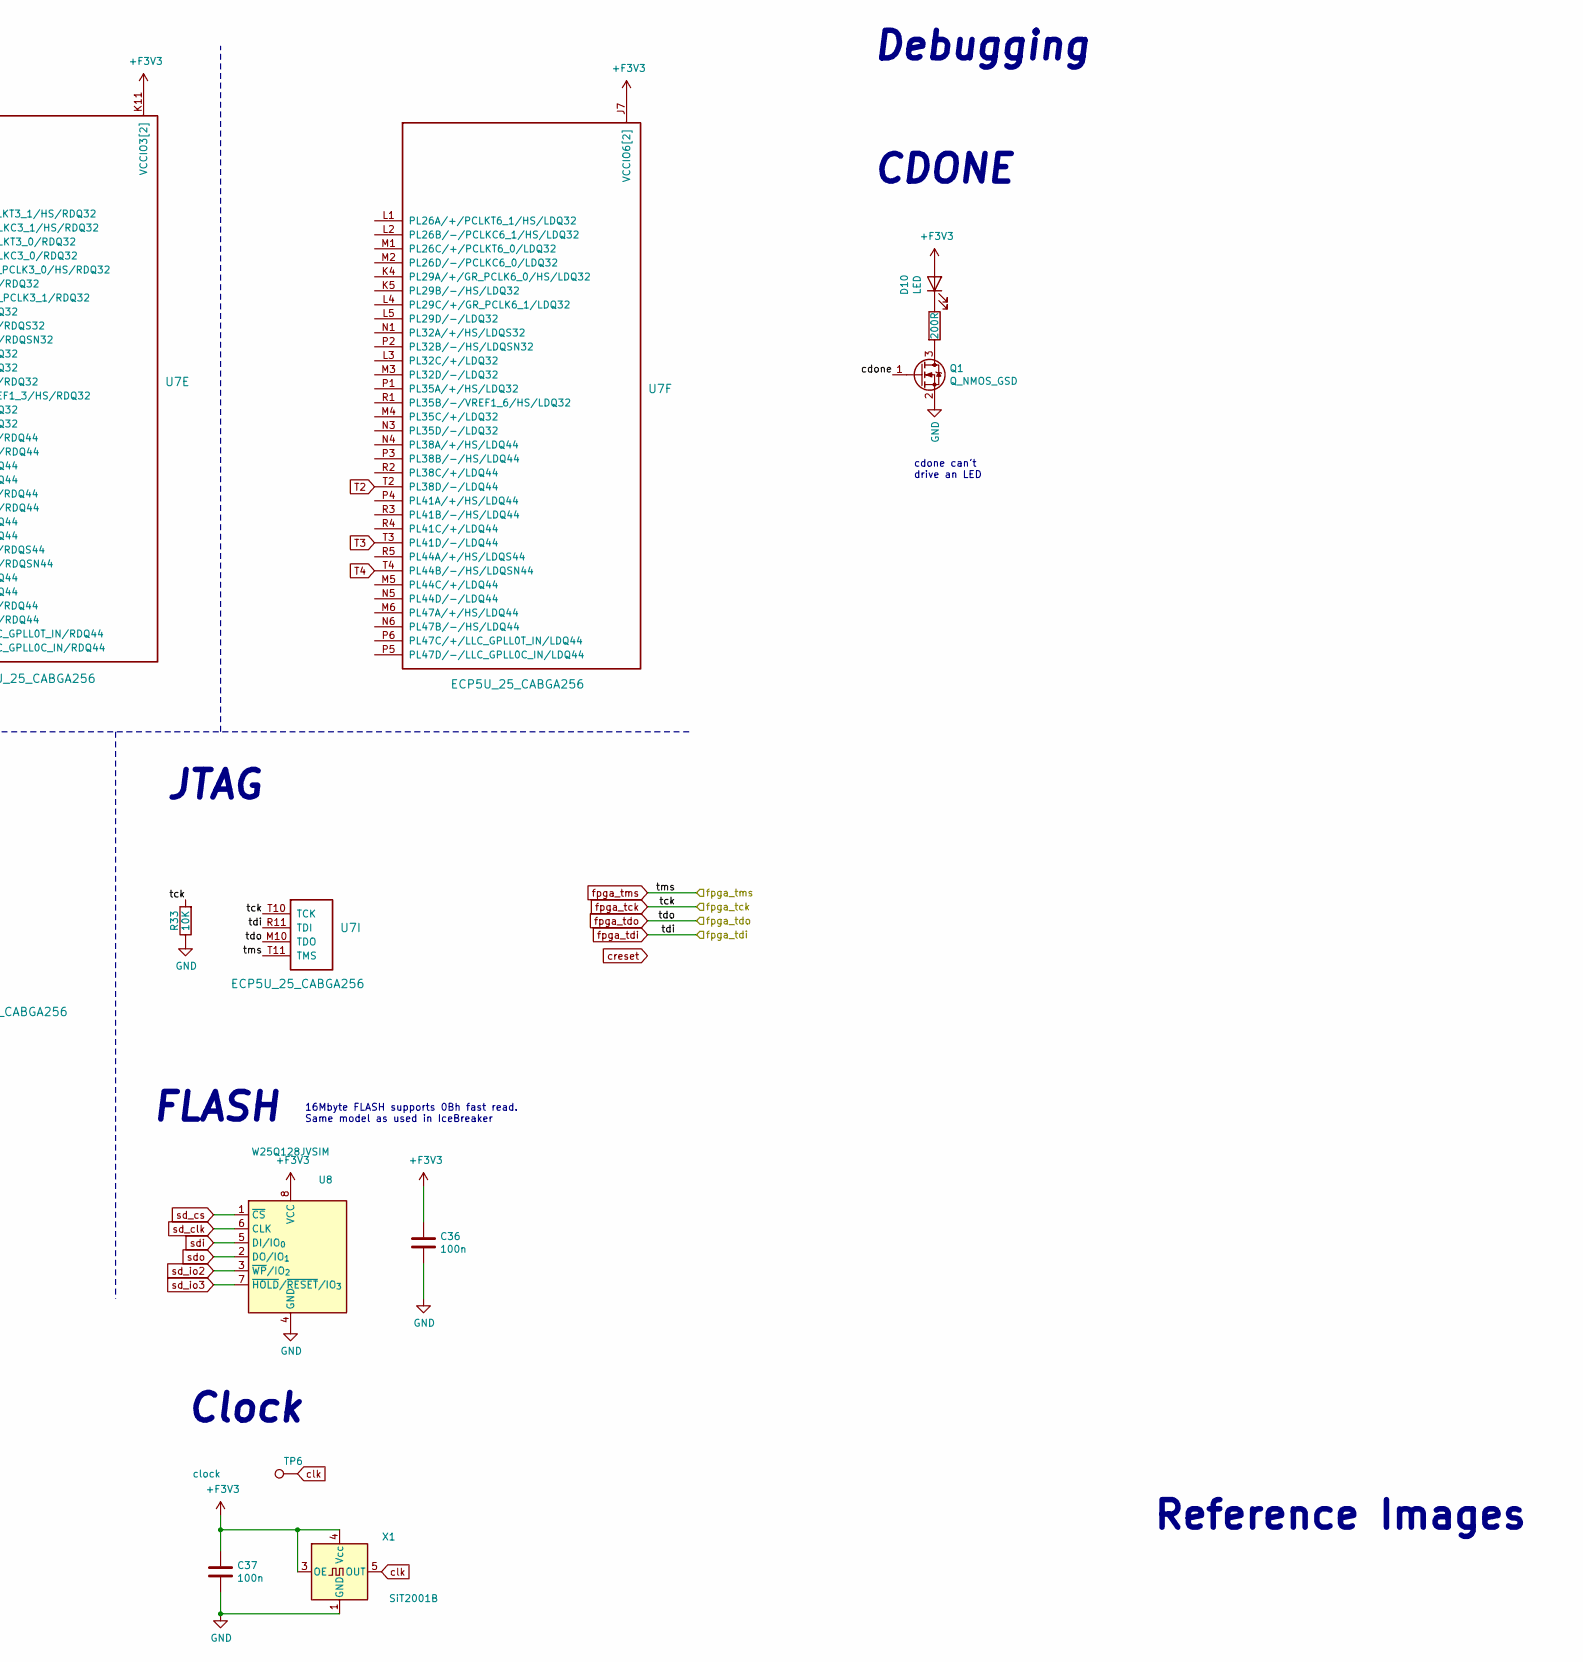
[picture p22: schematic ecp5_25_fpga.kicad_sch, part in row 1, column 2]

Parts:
C36, C37: 100n; C_0402_1005Metric
D10: LED; LED_0805_2012Metric
Q1: Q_NMOS_GSD; SOT-23
R32: 200R; R_0805_2012Metric
R33, R34, R35, R36, R37, R38, R39, R40, R41: 10K; R_0603_1608Metric_Pad0.98x0.95mm_HandSolder
TP6: clock; TestPoint_THTPad_D1.0mm_Drill0.5mm
U7: ECP5U_25_CABGA256; BGA-256_14.0x14.0mm_Layout16x16_P0.8mm_Ball0.45mm_Pad0.32mm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
U8: W25Q128JVSIM; SOIC-8_5.3x5.3mm_P1.27mm
X1: SiT2001B; SOT-23-5

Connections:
+F1V1: U7.G6 (VCC[6]), U7.G7 (VCC[6]), U7.G9 (VCC[6]), U7.L8 (VCC[6]), U7.L9 (VCC[6]), U7.L10 (VCC[6]); also elsewhere on the board
+F2V5: U7.G11 (VCCAUX[2]), U7.L7 (VCCAUX[2]); also elsewhere on the board
+F3V3: C36.1, C37.1, D10.2 (A), R35.2, R36.2, R37.2, R39.2, R40.2, R41.2, U7.F6 (VCCIO0[2]), U7.F7 (VCCIO0[2]), U7.F10 (VCCIO1[2]), U7.F11 (VCCIO1[2]), U7.H6 (VCCIO7[2]), U7.H7 (VCCIO7[2]), U7.H11 (VCCIO2[2]), U7.J6 (VCCIO6[2]), U7.J7 (VCCIO6[2]), U7.J11 (VCCIO2[2]), U7.K11 (VCCIO3[2]), U7.L6 (VCCIO8), U7.L11 (VCCIO3[2]), U8.8 (VCC), X1.3 (OE), X1.4 (Vcc); also elsewhere on the board
/ECP5_25K_FPGA/cfg_0: R34.1, U7.N10 (CFG_0)
/ECP5_25K_FPGA/cfg_1: R36.1, U7.P10 (CFG_1)
/ECP5_25K_FPGA/cfg_2: R38.1, U7.R10 (CFG_2)
A2: U7.A2 (PT4A/+)
A3: U7.A3 (PT6A/+); also elsewhere on the board
A4: U7.A4 (PT6B/-); also elsewhere on the board
A5: U7.A5 (PT18A/+); also elsewhere on the board
A6: U7.A6 (PT18B/-); also elsewhere on the board
A8: U7.A8 (PT29B/-/PCLKC0_0); also elsewhere on the board
A9: U7.A9 (PT42A/+); also elsewhere on the board
A10: U7.A10 (PT42B/-); also elsewhere on the board
A11: U7.A11 (PT53A/+); also elsewhere on the board
A12: U7.A12 (PT53B/-); also elsewhere on the board
A13: U7.A13 (PT65A/+); also elsewhere on the board
A14: U7.A14 (PT65B/-); also elsewhere on the board
B3: U7.B3 (PT4B/-)
B4: U7.B4 (PT11B/-); also elsewhere on the board
B5: U7.B5 (PT15B/-); also elsewhere on the board
B6: U7.B6 (PT22B/-); also elsewhere on the board
B8: U7.B8 (PT35B/-/PCLKC1_0); also elsewhere on the board
B9: U7.B9 (PT38A/+/GR_PCLK1_0); also elsewhere on the board
B10: U7.B10 (PT44A/+); also elsewhere on the board
B11: U7.B11 (PT49A/+); also elsewhere on the board
B12: U7.B12 (PT56A/+); also elsewhere on the board
B13: U7.B13 (PT60A/+); also elsewhere on the board
B14: U7.B14 (PT67A/+); also elsewhere on the board
C3: U7.C3 (PL2C/+/LDQ8); also elsewhere on the board
C4: U7.C4 (PT11A/+); also elsewhere on the board
C5: U7.C5 (PT15A/+); also elsewhere on the board
C6: U7.C6 (PT22A/+); also elsewhere on the board
C10: U7.C10 (PT44B/-)
C11: U7.C11 (PT49B/-)
C12: U7.C12 (PT56B/-)
C13: U7.C13 (PT60B/-)
C14: U7.C14 (PR2C/+/RDQ8)
CLKC1_1: U7.D8 (PT33B/-/PCLKC1_1)
CLKT1_0: U7.C8 (PT35A/+/PCLKT1_0)
CLKT1_1: U7.E8 (PT33A/+/PCLKT1_1)
D3: U7.D3 (PL2D/-/LDQ8); also elsewhere on the board
D4: U7.D4 (PT9B/-); also elsewhere on the board
D5: U7.D5 (PT13B/-); also elsewhere on the board
D6: U7.D6 (PT20B/-); also elsewhere on the board
D13: U7.D13 (PT62A/+)
D14: U7.D14 (PR2D/-/RDQ8)
E13: U7.E13 (PT62B/-)
E14: U7.E14 (PR5C/+/RDQ8)
GND: C36.2, C37.2, Q1.2 (S), R33.1, R34.2, R38.2, U7.A1 (GND[27]), U7.A16 (GND[27]), U7.D2 (GND[27]), U7.D15 (GND[27]), U7.F8 (GND[27]), U7.F9 (GND[27]), U7.G8 (GND[27]), U7.G10 (GND[27]), U7.H1 (GND[27]), U7.H8 (GND[27]), U7.H9 (GND[27]), U7.H10 (GND[27]), U7.H16 (GND[27]), U7.J8 (GND[27]), U7.J9 (GND[27]), U7.J10 (GND[27]), U7.K6 (GND[27]), U7.K7 (GND[27]), U7.K8 (GND[27]), U7.K9 (GND[27]), U7.K10 (GND[27]), U7.N2 (GND[27]), U7.N15 (GND[27]), U7.T1 (GND[27]), U7.T5 (GND[27]), U7.T12 (GND[27]), U7.T16 (GND[27]), U8.4 (GND), X1.1 (GND); also elsewhere on the board
GR_PCLK_1_1: U7.C9 (PT38B/-/GR_PCLK1_1)
unnamed: D10.1 (K), R32.1
unnamed: Q1.3 (D), R32.2
R12: U7.R12 (PR44A/+/HS/RDQS44)
R13: U7.R13 (PR41C/+/RDQ44)
R14: U7.R14 (PR41B/-/HS/RDQ44)
R15: U7.R15 (PR38C/+/RDQ44)
R16: U7.R16 (PR35B/-/VREF1_3/HS/RDQ32)
T2: U7.T2 (PL38D/-/LDQ44)
T3: U7.T3 (PL41D/-/LDQ44)
T4: U7.T4 (PL44B/-/HS/LDQSN44)
T13: U7.T13 (PR44B/-/HS/RDQSN44)
T14: U7.T14 (PR41D/-/RDQ44)
T15: U7.T15 (PR38D/-/RDQ44)
cdone: Q1.1 (G), U7.P9 (DONE)
clk: TP6.1, U7.A7 (PT29A/+/PCLKT0_0), X1.5 (OUT)
clk0_0: U7.D7 (PT24B/-/GR_PCLK0_0)
clk0_1: U7.E7 (PT24A/+/GR_PCLK0_1)
clkc0_1: U7.B7 (PT27B/-/PCLKC0_1)
clkt0_1: U7.C7 (PT27A/+/PCLKT0_1)
creset: R41.1, U7.R9 (PROGRAMN); also elsewhere on the board
fpga_tck: R33.2, U7.T10 (TCK); also elsewhere on the board
fpga_tdi: U7.R11 (TDI); also elsewhere on the board
fpga_tdo: U7.M10 (TDO); also elsewhere on the board
fpga_tms: U7.T11 (TMS); also elsewhere on the board
gp6: U7.T6 (PB4A/+/D7/IO7)
sd_clk: R35.1, U7.N9 (CCLK/MCLK/SCK), U8.6 (CLK)
sd_cs: R40.1, U7.N8 (PB15A/+/HOLDN/DI/BUSY/CSSPIN/CEN), U8.1 (~CS)
sd_io2: R39.1, U7.M7 (PB9B/-/D2/IO2), U8.3 (~WP/IO_{2})
sd_io3: R37.1, U7.N7 (PB9A/+/D3/IO3), U8.7 (~HOLD/~RESET/IO_{3})
sdi: U7.T7 (PB11A/+/D1/MISO/IO1), U8.5 (DI/IO_{0})
sdo: U7.T8 (PB11B/-/D0/MOSI/IO0), U8.2 (DO/IO_{1})

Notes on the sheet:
16Mbyte FLASH supports 0Bh fast read. Same model as used in IceBreaker
Config & SPI
PSU
Debugging
Reference Images
cfg[2:0] = 010. MSPI mode
CDONE
FLASH
cdone can't drive an LED
JTAG
Clock

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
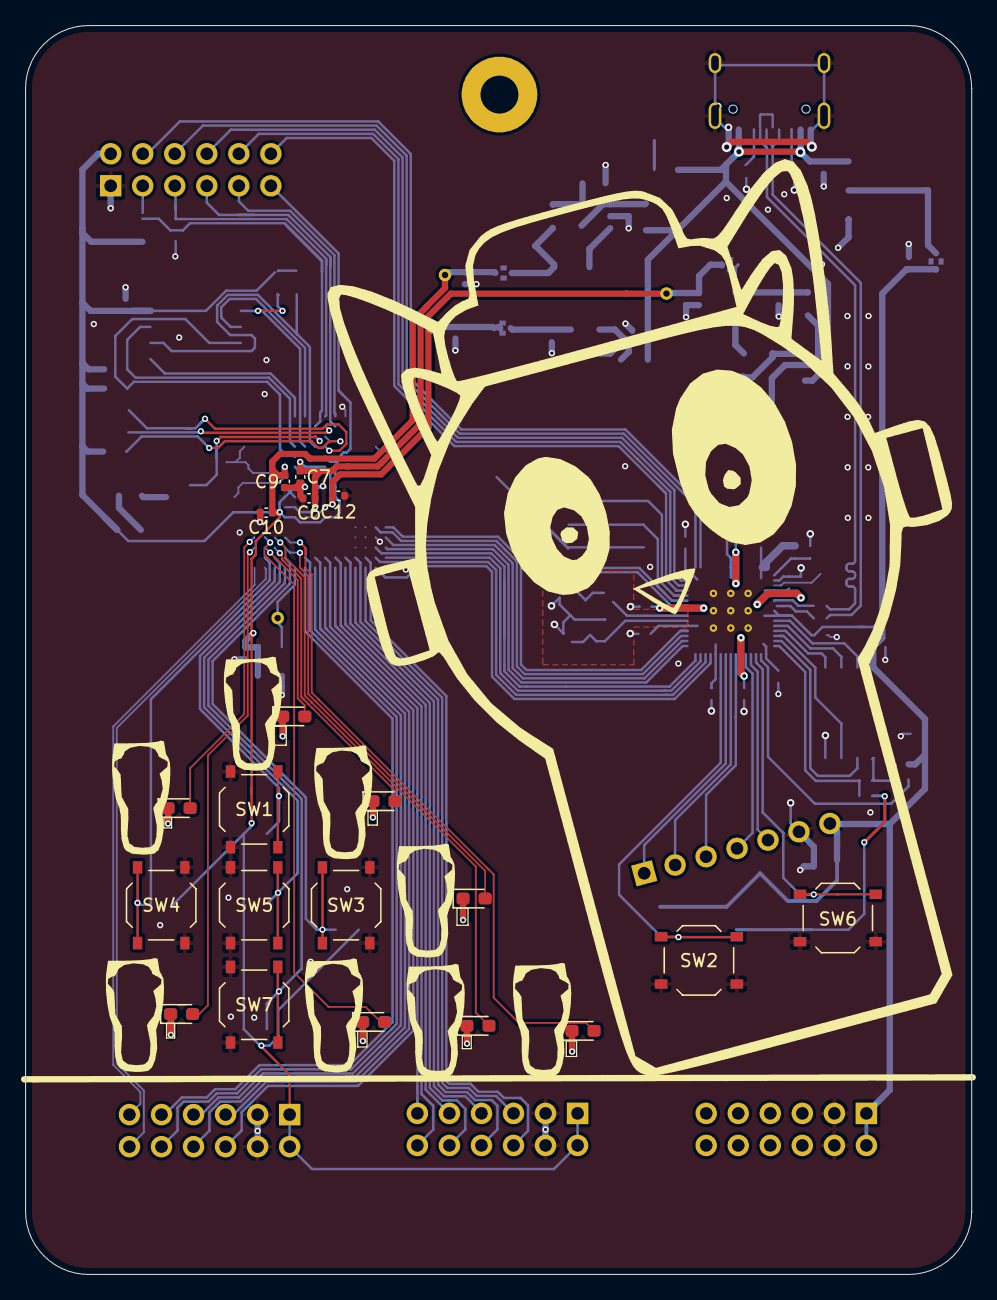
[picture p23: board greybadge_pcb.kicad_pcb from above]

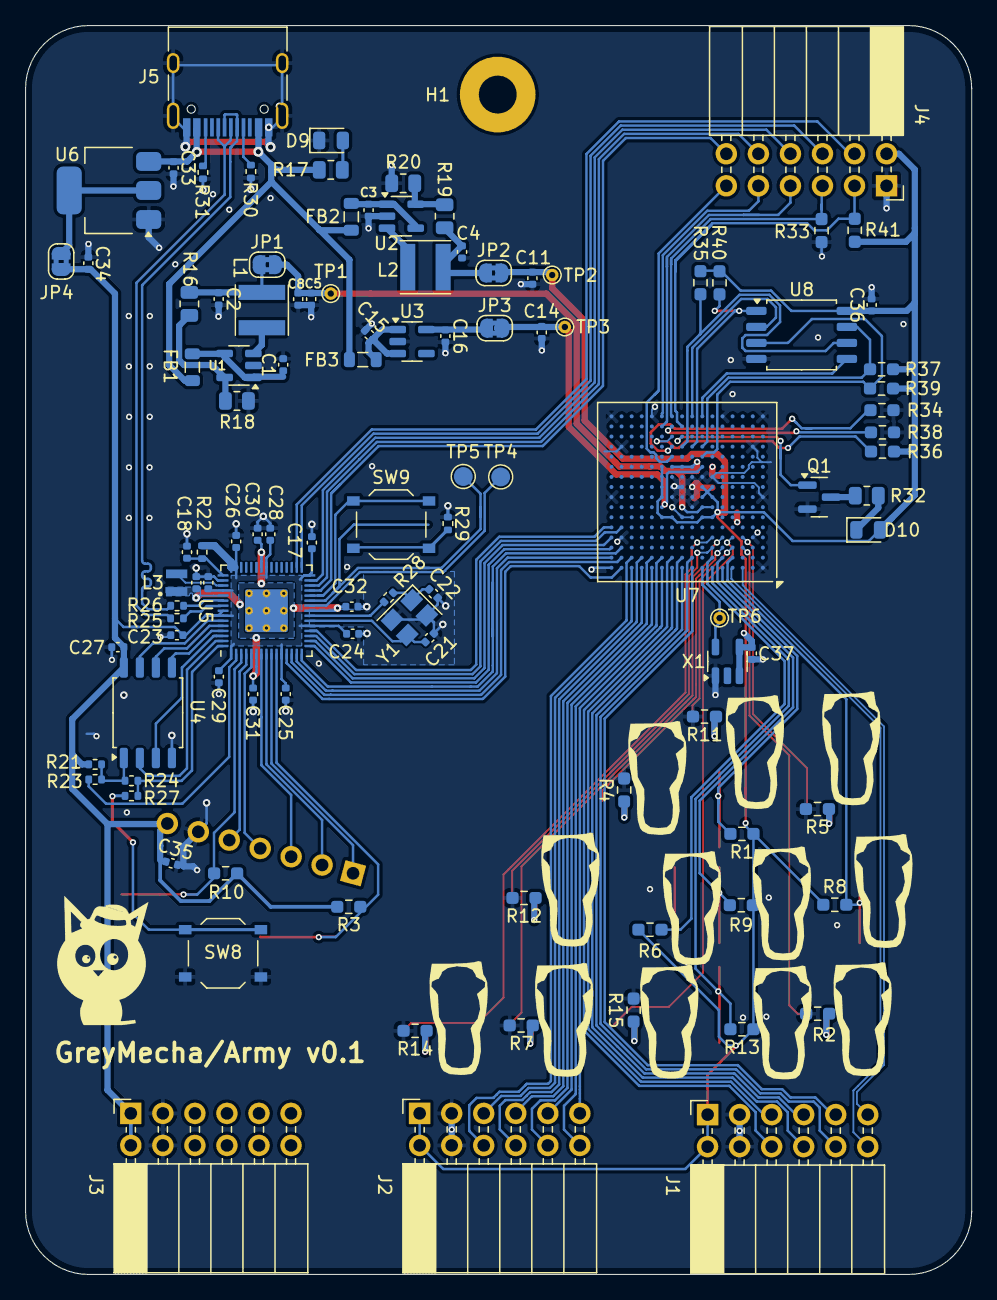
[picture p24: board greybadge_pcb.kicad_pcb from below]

Board: 2 copper layers, 75.0 x 99.0 mm, 130 parts (109 on the bottom side), 118 nets.

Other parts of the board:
R21: DNF; R_0402_1005Metric

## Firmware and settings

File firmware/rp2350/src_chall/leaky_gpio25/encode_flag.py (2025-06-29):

_KEY_A = bytes.fromhex("3c3eaf06" * 4)
_KEY_B = bytes.fromhex("8500ad20" * 4)
_KEY_C = bytes.fromhex("1996c0bc" * 4)

def _decrypt(data: bytes) -> bytes:
    """
    Branching decode:
      if high-bit set, use _KEY_A
      elif odd index, use _KEY_B
      else, use _KEY_C

    Then undo the little nonlinear mix (i*13)&0xFF.
    """
    out = bytearray(len(data))
    for i, c in enumerate(data):
        if c & 0x80: 
            k = _KEY_A[i % len(_KEY_A)]
        elif i & 1:
            k = _KEY_B[i % len(_KEY_B)]
        else:
            k = _KEY_C[i % len(_KEY_C)]
        x = c ^ k
        out[i] = x ^ ((i * 13) & 0xFF)
    return bytes(out)

def _encrypt(plaintext: bytes) -> bytes:
    """
    Invert the above: for each byte p at index i, compute x = p^mix,
    then try each key in the same order, checking the same branch
    conditions on the candidate ciphertext.
    """
    out = bytearray(len(plaintext))
    for i, p in enumerate(plaintext):
        mix = (i * 13) & 0xFF
        x = p ^ mix

        # 1) KEY_A branch
        kA = _KEY_A[i % len(_KEY_A)]
        cA = x ^ kA
        if cA & 0x80:
            out[i] = cA
            continue

        # 2) KEY_B branch (odd indices, low-bit)
        kB = _KEY_B[i % len(_KEY_B)]
        cB = x ^ kB
        if not (cB & 0x80) and (i & 1):
            out[i] = cB
            continue

        # 3) KEY_C branch (even indices, low-bit)
        kC = _KEY_C[i % len(_KEY_C)]
        cC = x ^ kC
        if not (cC & 0x80) and not (i & 1):
            out[i] = cC
            continue

        # If you see this, pick a different set of keys or tweak your scheme
        raise ValueError(f"No valid branch for byte index {i}")
    return bytes(out)

if __name__ == "__main__":
    FLAG = b"grey{N4n053c0nd_Pr3c1510n!}"
    encrypted = _encrypt(FLAG)
    print("Encrypted blob (hex):", encrypted.hex())

    # double check
    assert _decrypt(encrypted) == FLAG
    print("✔️  Round-trip OK.")

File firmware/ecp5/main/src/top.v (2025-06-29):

module top(
    input clk_ext, input [4:0] btn, output [7:0] led, 
    inout [7:0] interconnect, 
    inout [7:0] pmod_j1, inout [7:0] pmod_j2,
    inout [4:0] s // secret pins
);
    /// Internal Configuration ///////////////////////////////////////////
    wire clk_int;        // Internal OSCILLATOR clock
    defparam OSCI1.DIV = "3"; // Info: Max frequency for clock '$glbnet$clk': 162.00 MHz (PASS at 103.34 MHz)
    OSCG OSCI1 (.OSC(clk_int));

    wire clk = clk_int;
    localparam CLK_FREQ = 103_340_000; // EXT CLK

    // External Oscillator Easter egg /////
    reg clk_ext_soldered = 0;
    always @ (posedge clk_ext) begin clk_ext_soldered <= 1; end

    // Clock Configuration
    reg [31:0] clk_stepdown_counter = 0;
    reg [31:0] clk_stepdown_count_val = 5;
    reg clk_stepdown;
    always @ (posedge clk) begin
        clk_stepdown_counter <= clk_stepdown_counter + 1;
        if (clk_stepdown_counter >= clk_stepdown_count_val) begin
            clk_stepdown <= ~clk_stepdown;
            clk_stepdown_counter <= 0;
        end
    end

    /// PWM for Generic Control //////////////////////////////////////////
    reg [31:0] counter_pwm;
    reg [31:0] pwm_on_cycles = 1;
    reg [31:0] pwm_total_cycles = 4;
    reg pwm_out = 0;
    always @ (posedge clk) begin
        counter_pwm <= counter_pwm + 1;
        if (counter_pwm == pwm_on_cycles) begin
            pwm_out <= 0;
            //counter_pwm <= 0;
        end else if (counter_pwm >= pwm_total_cycles) begin
            pwm_out <= 1;
            counter_pwm <= 0;
        end
    end
    wire [7:0] pwm_bulk_out = {pwm_out, pwm_out, pwm_out, pwm_out, pwm_out, pwm_out, pwm_out, pwm_out};

    /// Chall: Shooting Flags ////////////////////////////////////////////
    wire [7:0] chall_shootingflags_leds;
    shooting_flags #(.CLK_FREQ(CLK_FREQ)) chall_shootingflags (
        .clk(clk), 
        .got_commanding_officer(~btn[2]),
        .cats(chall_shootingflags_leds)
    );

    /// Chall: SecureMemory /////////////////////////////////////////////////////
    reg chall_secmem_clk = 0; // 10hz clock
    reg [31:0] chall_secmem_clk_counter = 0; 
    always @ (posedge clk) begin
        chall_secmem_clk_counter <= chall_secmem_clk_counter + 1;
        if (chall_secmem_clk_counter >= CLK_FREQ/20) begin
            chall_secmem_clk <= ~chall_secmem_clk;
            chall_secmem_clk_counter <= 0;
        end
    end
    wire [4:0] chall_secmem_address;
    wire [7:0] chall_secmem_value;
    secure_memory chall_secmem(
        .clk(chall_secmem_clk), 
        .address(chall_secmem_address), 
        .value(chall_secmem_value)
    );
    
    /// Chall: Fun SecureMemory /////////////////////////////////////////////////////
    reg chall_fast_secmem_clk = 0; // 50mhz clock
    always @ (posedge clk) begin
        chall_fast_secmem_clk <= ~chall_fast_secmem_clk;
    end
    wire [4:0] chall_fast_secmem_address;
    wire [7:0] chall_fast_secmem_value;
    fast_secure_memory chall_fast_secmem(
        .clk(chall_fast_secmem_clk), 
        .address(chall_fast_secmem_address), 
        .value(chall_fast_secmem_value)
    );

    /// UART ////////////////////////////////////////////////////////////
    parameter DBITS = 8;
    parameter UART_FRAME_SIZE = 18;
    
    // Outputs
    wire rx; 
    wire tx;
    // Control
    wire reset = ~btn[2];
    wire rx_full, rx_empty;
    wire tx_trigger;
    // Data
    reg  [UART_FRAME_SIZE*DBITS-1:0] uart_tx_out;
    wire [UART_FRAME_SIZE*DBITS-1:0] rx_out;

    // Complete UART Core
    uart_top 
        #(
            .FIFO_IN_SIZE(UART_FRAME_SIZE),
            .FIFO_OUT_SIZE(UART_FRAME_SIZE),
            .FIFO_OUT_SIZE_EXP(32), 
            .BR_LIMIT(672), 
            .BR_BITS(10)
        ) 
        UART_UNIT
        (
            .clk_100MHz(clk),
            .reset(reset),
            
            .rx(rx),
            .tx(tx),
            
            .rx_full(rx_full),
            .rx_empty(rx_empty),
            .rx_out(rx_out),
            
            .tx_trigger(tx_trigger),
            .tx_in(uart_tx_out)
        );

    // posedge detector for tx_trigger
    reg  tx_controller_send = 0;
    wire tx_trigger_pe;
    assign tx_trigger = ~btn[3] | tx_trigger_pe;
    pos_edge_det UART_TRIGGER_UNIT (.sig(tx_controller_send), .clk(clk), .pe(tx_trigger_pe));

    // RX handling
    assign rx = (mode == MODE_UART ? interconnect[0] : 1'b1);

    /// CatCore ///////////////////////////////////////////////////////////////////////
    wire catcore_devmode_input = s[0]; //cs
    reg catcore_devmode_counter = 0;
    reg catcore_devmode = 0;
    always @ (posedge clk) begin
        if (catcore_devmode_counter == 0 && catcore_devmode_input == 0) begin
            catcore_devmode <= 1;
        end
        catcore_devmode_counter <= 1;
    end


    
    parameter ADMIN_KEY = "1234567890123456";
    //// CatCore Memory manager (For Debugging)    
    wire [3:0] chall_catcore_address = pmod_j1[3:0];
    reg [3:0] chall_catcore_address_reg = 0;
    reg [127:0] chall_catcore_value;
    always @ (*) begin
        case (chall_catcore_address)
            0: chall_catcore_value = "developerkeypowers"; // Developer key
            1: chall_catcore_value = "i am only developer"; // Admin key
            2: chall_catcore_value = "lmao i lame 2"; // Admin key
            3: chall_catcore_value = "lmao i lame 3"; // Admin key
            4: chall_catcore_value = "lmao i lame 4"; // Admin key
            5: chall_catcore_value = "lmao i lame 5"; // Admin key
            6: chall_catcore_value = "lmao i lame 6"; // Admin key
            7: chall_catcore_value = "lmao i lame 7"; // Admin key

            8: chall_catcore_value = "DA1w4n7myfl49p15DA"; // Admin key
            8 + 1: chall_catcore_value = "i admin i power"; // Admin key
            8 + 2: chall_catcore_value = ADMIN_KEY; 
            15: chall_catcore_value = ADMIN_KEY; 
            default: chall_catcore_value = 127'b0;
        endcase
    end



    //// CatCore LED Controller
    reg catcore_led_inuse = 0;
    reg [7:0] catcore_led_register = 8'b11111111;

    //// CatCore Hyper - Super Hyper Mode
    reg         catcore_hyper_start = 0;
    reg [127:0] catcore_hyper_instruction_in;

    reg        catcore_hyper_started = 0;
    parameter CATCORE_HYPER_STAGE_IDLE = 0;
    parameter CATCORE_HYPER_STAGE_DECODE = 1;
    parameter CATCORE_HYPER_STAGE_RUN = 2;
    reg [1:0]   catcore_hyper_stage = CATCORE_HYPER_STAGE_IDLE;
    reg [127:0] catcore_hyper_instruction;
    reg [127:0] catcore_hyper_instruction_decrypted; 

    parameter CATCORE_HYPER_INSTR_DEV  = "@";
    parameter CATCORE_HYPER_INSTR_DEV_MEMORY  = "C";
    parameter CATCORE_HYPER_INSTR_FLAG = "A";
    parameter CATCORE_HYPER_INSTR_LED  = "B";
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

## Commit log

2025-02-22 feat: base project
    [AMS1117-3.3.step, greybadge_pcb.kicad_pcb, greybadge_pcb.kicad_sch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]
2025-02-22 feat: linking tinyfpga stuff
    [greybadge_pcb.kicad_pcb]
2025-02-22 feat: arrangement
    [greybadge_pcb.kicad_pcb]
2025-02-24 Update kicad libs
    [RP2350_QFN80.step]
2025-02-24 Update sch and pcb
    [greybadge_pcb.kicad_pcb, greybadge_pcb.kicad_sch, rp2350.kicad_sch]
2025-03-03 Update routing
    [greybadge_pcb.kicad_pcb]
2025-03-03 Add screen
    [greybadge_pcb.kicad_pcb]
2025-03-03 Update routing and zones
    [greybadge_pcb.kicad_pcb]
2025-03-03 Update routing/zones
    [greybadge_pcb.kicad_pcb]
2025-03-09 feat: fpga schematic
    [ecp5_25_fpga.kicad_sch, greybadge_pcb.kicad_pcb, greybadge_pcb.kicad_sch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]
2025-03-12 feat: rough component placement
    [ecp5_25_fpga.kicad_sch, greybadge_pcb.kicad_pcb, greybadge_pcb.kicad_sch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]
2025-03-16 feat: bga and mcu routing
    [ecp5_25_fpga.kicad_sch, greybadge_pcb.kicad_pcb, greybadge_pcb.kicad_sch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]
2025-03-16 feat: pcb routing and stuff
    [ecp5_25_fpga.kicad_sch, greybadge_pcb.kicad_pcb, greybadge_pcb.kicad_sch]
2025-03-17 Minor cleanups
    [greybadge_pcb.kicad_pcb]
2025-03-17 Update badge
    [greybadge_pcb.kicad_pcb, greybadge_pcb.kicad_sch]
2025-03-19 Fix annotation
    [ecp5_25_fpga.kicad_sch, greybadge_pcb.kicad_sch, rp2350.kicad_sch]
2025-03-23 feat: leds
    [ecp5_25_fpga.kicad_sch, greybadge_pcb.kicad_pcb, greybadge_pcb.kicad_sch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]
2025-03-23 feat: routing cleanupish, power splitting and drc
    [ecp5_25_fpga.kicad_sch, greybadge_pcb.kicad_pcb, greybadge_pcb.kicad_sch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]
2025-03-23 feat: played around with jlc bom
    [greybadge_pcb.kicad_pcb]
2025-03-27 Clean up PCB
    [ecp5_25_fpga.kicad_sch, greybadge_pcb.kicad_pcb, greybadge_pcb.kicad_sch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]
2025-03-28 Update PCB and add JLC files
    [ecp5_25_fpga.kicad_sch, greybadge_pcb.kicad_pcb, greybadge_pcb.kicad_sch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]
2025-03-28 Update inductor choice for rp2350
    [greybadge_pcb.kicad_pcb]
2025-03-28 Minor silkscreen ref update
    [greybadge_pcb.kicad_pcb]
2025-03-28 Fix 10ohm resistor bom
    [greybadge_pcb.kicad_pcb]
2025-03-28 Fix 10kohm resistor BOM
    [greybadge_pcb.kicad_pcb]
2025-03-28 Fix BOM
2025-04-20 Update bom
    [greybadge_pcb.kicad_pcb]
2025-04-30 Remove LDO and reroute power
    [ecp5_25_fpga.kicad_sch, greybadge_pcb.kicad_pcb, greybadge_pcb.kicad_sch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]
2025-05-01 feat: doodlecat
    [greybadge_pcb.kicad_pcb]
2025-05-01 feat: buzzer etc.
    [greybadge_pcb.kicad_pcb, greybadge_pcb.kicad_sch]
2025-05-01 feat: arms
    [greybadge_pcb.kicad_pcb]
2025-05-07 extend greymecha
    [greybadge_pcb.kicad_pcb]
2025-05-07 feat: nsf section
    [greybadge_pcb.kicad_pcb]
2025-05-07 feat: oled move to top sch
    [ecp5_25_fpga.kicad_sch, greybadge_pcb.kicad_pcb, greybadge_pcb.kicad_sch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]
2025-05-07 feat: oled to fpga
    [ecp5_25_fpga.kicad_sch, greybadge_pcb.kicad_pcb, greybadge_pcb.kicad_sch]
2025-05-08 feat: artwork positioning i think
    [greybadge_pcb.kicad_pcb]
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2025-05-08 feat: rough sync framework - might make a custom one
2025-05-08 feat: add lipo support
    [ecp5_25_fpga.kicad_sch, greybadge_pcb.kicad_pcb, greybadge_pcb.kicad_sch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]
2025-05-08 feat: Add pads for AA batt
    [ecp5_25_fpga.kicad_sch, greybadge_pcb.kicad_pcb, greybadge_pcb.kicad_sch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]
2025-05-08 Fix: Use 10k Ohm for R to fix backlight dimming on button press
    [ecp5_25_fpga.kicad_sch, greybadge_pcb.kicad_pcb, greybadge_pcb.kicad_sch]
2025-05-08 Fix: battery/power and clean up silkscreen references
    [ecp5_25_fpga.kicad_sch, greybadge_pcb.kicad_pcb, greybadge_pcb.kicad_sch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]
2025-05-08 Update fpga osc to use 2v5
    [ecp5_25_fpga.kicad_sch, greybadge_pcb.kicad_pcb, greybadge_pcb.kicad_sch]
2025-05-08 Add onboard oled (incomplete)
    [ecp5_25_fpga.kicad_sch, greybadge_pcb.kicad_pcb, greybadge_pcb.kicad_sch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]
2025-05-08 Update to on-board OLED
    [greybadge_pcb.kicad_pcb, greybadge_pcb.kicad_sch]
2025-05-09 feat: uart sample code
2025-05-09 feat: oled + jtag
    [ecp5_25_fpga.kicad_sch, greybadge_pcb.kicad_pcb, greybadge_pcb.kicad_sch]
2025-05-09 Route buzzer, improve routing/silkscreen ref
    [ecp5_25_fpga.kicad_sch, greybadge_pcb.kicad_pcb, greybadge_pcb.kicad_sch]
2025-05-09 Remove USB LED, add LED charging indicator
    [ecp5_25_fpga.kicad_sch, greybadge_pcb.kicad_pcb, greybadge_pcb.kicad_sch]
2025-05-09 Fix prev commit
    [ecp5_25_fpga.kicad_sch, greybadge_pcb.kicad_sch, rp2350.kicad_sch]
2025-05-10 feat: shift button resistors
    [ecp5_25_fpga.kicad_sch, greybadge_pcb.kicad_pcb, greybadge_pcb.kicad_sch]
2025-05-10 feat: stuff
    [ecp5_25_fpga.kicad_sch, greybadge_pcb.kicad_pcb, greybadge_pcb.kicad_sch]
2025-05-11 Route ADC and power, cleanup routing/silkscreen
    [ecp5_25_fpga.kicad_sch, greybadge_pcb.kicad_pcb, greybadge_pcb.kicad_sch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]
2025-05-11 Remove collinear tracks
    [greybadge_pcb.kicad_pcb]
2025-05-11 Update font sizes
    [greybadge_pcb.kicad_pcb]
2025-05-11 feat: saf section
    [greybadge_pcb.kicad_pcb]
2025-05-12 feat: back silkscreen
    [ecp5_25_fpga.kicad_sch, greybadge_pcb.kicad_pcb, greybadge_pcb.kicad_sch]
2025-05-12 feat: to send out?
    [greybadge_pcb.kicad_pcb]
2025-05-12 Cleanup routing/silkscreen
    [greybadge_pcb.kicad_pcb]
2025-05-12 Update for ordering
    [ecp5_25_fpga.kicad_sch, greybadge_pcb.kicad_pcb, greybadge_pcb.kicad_sch]
2025-05-12 Fix components
    [ecp5_25_fpga.kicad_sch, greybadge_pcb.kicad_pcb, greybadge_pcb.kicad_sch]
2025-05-17 feat: uart is painful
2025-05-17 feat: can synthesize but not working
    [tmp.v, top.v, uart_top.v]
2025-05-17 feat: uart might be working, it might be an rp2350 issue
    [top.v]
2025-05-17 feat: uart works but only for null bytes
2025-05-18 feat: documentation of simple uart
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2025-05-21 Fix: charging indicator
    [ecp5_25_fpga.kicad_sch, greybadge_pcb.kicad_pcb, greybadge_pcb.kicad_sch]
2025-05-23 fix: rp2350 flash
    [greybadge_pcb.kicad_pcb, rp2350.kicad_sch]
2025-05-23 Fix silkscreen
    [greybadge_pcb.kicad_pcb]
2025-05-23 art: new mecha cat
    [greybadge_pcb.kicad_pcb]
2025-05-23 feat: oscillator power switch
    [ecp5_25_fpga.kicad_sch, greybadge_pcb.kicad_pcb, greybadge_pcb.kicad_sch]
2025-05-23 feat: rp2350 schematic update for flash
    [ecp5_25_fpga.kicad_sch, greybadge_pcb.kicad_pcb, greybadge_pcb.kicad_sch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]
2025-05-23 fix: remove excess trace
    [greybadge_pcb.kicad_pcb]
2025-05-25 art: increase text size
    [greybadge_pcb.kicad_pcb]
2025-05-25 art: label text width adjustment
    [greybadge_pcb.kicad_pcb]
2025-05-25 feat: filled ears + removed oscillator mapping
    [greybadge_pcb.kicad_pcb]
2025-05-25 coloured ears
    [greybadge_pcb.kicad_pcb]
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2025-06-09 feat: uart temp fix - need debug more for sending etc.
    [top.v]
2025-06-14 feat: uart bug
2025-06-15 Add leaky_gpio25 and restructure challenges
    [encode_flag.py, leaky_gpio25.py]
2025-06-19 feat: apparently uart fifo wasnt working this whole time wtf?
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2025-06-20 fix: sets (only led[0]), clears, checks packet format
    [top.v]
2025-06-20 feat: bruh my math was wrong, it just works now
    [top.v]
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2025-06-21 module put in but not working properly
    [top.v]
2025-06-23 Fix stdout for leaky_gpio
    [leaky_gpio25.py]
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2025-06-25 fix: catcore led instruction
    [top.v]
2025-06-25 help: theres a short circuit here somewhere, need to fix ASAP
    [top.v]
2025-06-25 managed to get that glitching working eh
    [top.v]
2025-06-25 fix: remove aes and fix heating issue
    [top.v]
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2025-07-02 its the writing that has issues
    [top.v]
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2025-07-02 uart in coprocessor fixed
    [top.v, uart_top.v]
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
